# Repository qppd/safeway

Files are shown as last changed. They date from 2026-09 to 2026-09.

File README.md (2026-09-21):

# SafeWay

**An IoT-Based Vehicle Speed Monitoring and Data Logging System for a Campus Security & Safety Unit**

SafeWay is a low-cost, institutional-scale vehicle speed monitoring system. A 24 GHz Doppler radar measures vehicle speed directly on a campus road; a two-board ESP32 design photographs the vehicle, serves a live lane feed, logs the incident to a cloud database via API, and sounds a buzzer when the speed limit is exceeded. Security personnel monitor everything from a web dashboard — in real time.

> Proof-of-concept capstone project (April 2026)

---

## Table of Contents

- [About](#about)
- [How It Works](#how-it-works)
- [Features](#features)
- [Hardware](#hardware)
- [System Architecture](#system-architecture)
- [Repository Structure](#repository-structure)
- [Build Guide](#build-guide)
- [Quick Start (TL;DR)](#quick-start-tldr)
- [Evaluation Criteria](#evaluation-criteria)
- [Documentation Index](#documentation-index)
- [Team](#team)
- [Acknowledgment](#acknowledgment)

## About

Overspeeding inside institutional campuses is monitored manually — by visual observation and paper logging — which is inconsistent and unreliable. Commercial speed-enforcement systems (radar, ANPR cameras) are engineered for highways and priced beyond what small institutions can afford.

SafeWay answers that gap with a **proof-of-concept** built from ~₱2,328 worth of off-the-shelf IoT parts: it measures speed with radar physics, captures evidence, recognizes plate numbers, logs to the cloud, and surfaces violations on a dashboard with a live camera feed — at institutional scale and budget.

Pilot client: a university **Security & Safety Unit (SSU)**. Development follows the **PPDIOO** lifecycle (Prepare, Plan, Design, Implement, Operate, Optimize).

## How It Works

```
Speed = Doppler frequency ÷ 44.7 Hz-per-km/h
```

1. A vehicle enters the radar beam of the **CDM324 24 GHz Doppler module** (mounted on a single pole along the lane)
2. The radar's IF output frequency is **directly proportional to speed** — the ESP32 hub counts pulses, converts Hz → km/h, and holds the **peak** reading for the event
3. Two **KY-008 laser break-beams** across the lane (transmitters on the far post, each on its own supply; receivers on the hub pole) confirm a vehicle is physically present (rejects phantom radar triggers from branches/pedestrians)
4. If peak speed > limit (e.g. 30 km/h campus limit — `SPEED_LIMIT_KPH`):
   - **Buzzer** sounds a live warning while the vehicle is over the limit
   - **Beam #2 breaks → the ESP32-S3 CAM board grabs the photo itself** (vehicle **at the pole**, plate in frame) and caches it; beam #1 breaks → the hub fetches that cached beam-moment frame from `/capture`; the CAM also saves it to microSD
   - When the lane clears, the incident record (speed, raw Doppler Hz, confirm flag, photo) is **POSTed to the cloud API**
5. SSU personnel watch the **live lane feed** and review violations on the dashboard; plate numbers are read from captured photos for record accuracy

## Features

- **Doppler radar speed detection** — direct physical measurement: speed is read from the Doppler shift itself, not timed between two gates
- **Two-board architecture** — 38-pin ESP32 hub owns all sensors; ESP32-S3 CAM owns imaging. WiFi between them, no data cables
- **Live lane feed** — SSU sees the monitored road from the dashboard (polled ~1 frame/s)
- **Dual-sensor confirmation** — radar + laser break-beam agreement flags each incident (evidence-grade: raw Doppler Hz stored with every record)
- **Beam-triggered plate capture** — the camera self-triggers at its own break-beam: zero HTTP latency, car at the pole, plate in frame
- Photo evidence capture with microSD backup logging
- Cloud data logging through REST API integration
- On-site audible overspeed alert (active buzzer)
- Web dashboard for authorized SSU personnel
- Plate number recognition from captured images
- ~₱2,328 prototype cost vs. commercial radar/ANPR systems

## Hardware

Core components (full verified shopping list with Lazada PH links, prices, and ratings: **[docs/BOM.md](docs/BOM.md)**):

| Component | Role |
|---|---|
| CDM324 24 GHz Doppler radar | Speed measurement (IF frequency = 44.7 Hz per km/h) |
| ESP32 38-pin dev board | Sensor hub — pulse counting, beam #1 confirm, buzzer, cloud upload |
| ESP32-S3 WROOM N16R8 CAM + OV5640 | Camera board — beam #2 self-triggered snapshots, polled live feed, microSD backup |
| KY-008 laser TX + receiver pairs ×2 | Beam #1: presence confirmation (hub GPIO 25) · Beam #2: CAM snapshot trigger (GPIO 21) — far-post TXs, hub-pole receivers |
| Active buzzer 5V | Overspeed alert |
| microSD 16GB Class 10 | Local photo backup on the CAM board |
| LM358 op-amp | Radar signal conditioner — CDM324 → LM358 → GPIO 34 (see [HARDWARE.md §4](docs/HARDWARE.md#4-lm358-signal-conditioner-radar-chain)) |
| 5V 2A adapters ×2 + USB chargers ×2 (far post) + 18650 UPS backup per supply (16 cells, 4 devices, 4 h runtime) + IP68 enclosure + breadboard, jumpers, zip ties | Four independent supplies with battery backup, weatherproofing, assembly |

**Complete wiring diagram:** [wiring/circuit_image.png](wiring/circuit_image.png) — every module, pin, and power rail in one picture; visual companion to the pin-by-pin tables in [HARDWARE.md](docs/HARDWARE.md) (editable in [Cirkit Designer](https://app.cirkitdesigner.com/project/192cfce5-5705-47b2-8c56-7a07da66e9da)).

## System Architecture

```mermaid
flowchart TB
    RADAR["CDM324 Doppler radar<br/>IF = 44.7 Hz per km/h"]
    BEAM1["KY-008 pair #1<br/>break-beam across lane"]
    BEAM2["KY-008 pair #2<br/>break-beam across lane (offset)"]
    HUB["ESP32 38-pin HUB — sensors<br/>radar → GPIO 34 · beam #1 → GPIO 25 · buzzer → GPIO 27<br/>peak speed = Hz ÷ 44.7 ÷ cos(mount angle)"]
    CAM["ESP32-S3 WROOM CAM (OV5640)<br/>beam #2 → GPIO 21 → self-triggered snapshot<br/>/capture → cached plate frame + SD save<br/>/stream → polled live frame"]
    API["Cloud API + Database<br/>incident records + photos<br/>plate number recognition"]
    DASH["Monitoring Dashboard (SSU)<br/>live lane feed + violation table + photo pane"]

    RADAR --> HUB
    BEAM1 --> HUB
    BEAM2 --> CAM
    HUB -- "WiFi — fetch cached beam photo, JSON POST" --> CAM
    HUB -- "violation event" --> API
    CAM -- "live feed" --> DASH
    API --> DASH
```

Details: [docs/BLOCK-DIAGRAM.md](docs/BLOCK-DIAGRAM.md) · [docs/SYSTEM-ARCHITECTURE.md](docs/SYSTEM-ARCHITECTURE.md) · [docs/FLOWCHART.md](docs/FLOWCHART.md)

## Repository Structure

```
safeway/
├── README.md               ← you are here
├── docs/
│   ├── BOM.md              ← verified parts list (Lazada PH)
│   ├── HARDWARE.md         ← wiring, power, enclosure assembly
│   ├── FIRMWARE.md         ← both firmware sketches, flashing, tuning
│   ├── BACKEND.md          ← cloud API, database, dashboard
│   ├── TESTING.md          ← calibration & accuracy tests
│   ├── DEPLOYMENT.md       ← site installation guide
│   ├── STACK.md            ← full technology stack reference
│   ├── BLOCK-DIAGRAM.md    ← hardware blocks & signal chains
│   ├── FLOWCHART.md        ← runtime decision logic
│   ├── SYSTEM-ARCHITECTURE.md ← layers, interfaces, failure modes
├── wiring/
│   └── circuit_image.png               ← full circuit diagram (Cirkit Designer)
│   └── CDM324_LM358_ESP32_Testing_Guide.md  ← step-by-step LM358 build & test guide
├── .gitignore              ← repo hygiene rules
└── LICENSE                 ← CC BY 4.0
```

## Build Guide

The complete build is organized into six stage guides. Follow them in order:

| Step | Guide | What you'll do |
|---:|---|---|
| 1 | **[docs/HARDWARE.md](docs/HARDWARE.md)** | Verify the radar's IF output, wire the hub (radar + laser break-beam #1 + buzzer) and the CAM (break-beam #2 → GPIO 21), set up the CAM board, assemble into the enclosure |
| 1a | **[wiring/CDM324_LM358_ESP32_Testing_Guide.md](wiring/CDM324_LM358_ESP32_Testing_Guide.md)** | Step-by-step LM358 signal conditioner build & test — power, 2.5V bias, Stage 1 & 2 amps, radar input, comparator gate before connecting to ESP32 GPIO34 |
| 2 | **[docs/FIRMWARE.md](docs/FIRMWARE.md)** | Set up Arduino IDE, flash both boards (camera server + sensor hub), tune speed limit + angles |
| 3 | **[docs/BACKEND.md](docs/BACKEND.md)** | Stand up the cloud API + database + monitoring dashboard with live feed |
| 4 | **[docs/TESTING.md](docs/TESTING.md)** | Bench-test each board, calibrate Doppler accuracy, run the ISO-based evaluation |
| 5 | **[docs/DEPLOYMENT.md](docs/DEPLOYMENT.md)** | Site survey, pole-mount at the pilot road, train SSU users, maintenance plan |

Each guide is self-contained with wiring tables, commands, and checklists.

## Quick Start (TL;DR)

```bash
git clone https://github.com/qppd/safeway.git
```

1. Order parts from [docs/BOM.md](docs/BOM.md) (~₱2,328 recommended build)
2. Wire per [HARDWARE.md](docs/HARDWARE.md) → flash both boards per [FIRMWARE.md](docs/FIRMWARE.md)
3. Launch the API per [BACKEND.md](docs/BACKEND.md), point the hub firmware at it
4. Drive past the pole — verify speed reading + photo + dashboard record + live feed

## Evaluation Criteria

Per the capstone methodology, the prototype is evaluated on:

| Criterion | Measure |
|---|---|
| Accuracy | Correct speed detection and recorded data |
| Response Time | Detection → alert + data transmission latency |
| Reliability | Consistency across repeated tests |
| Usability | Dashboard ease-of-use for SSU personnel |
| Data Accessibility | Real-time record retrieval |

Software quality is assessed against **ISO/IEC 25010** and the IoT architecture against **ISO/IEC 30141**. See [docs/TESTING.md](docs/TESTING.md).

## Documentation Index

| Document | Contents |
|---|---|
| [BOM.md](docs/BOM.md) | Verified Lazada PH parts, prices, ratings, seller links, budget variants |
| [HARDWARE.md](docs/HARDWARE.md) | Two-board pin map, wiring tables, power design, enclosure, radar aiming |
| [FIRMWARE.md](docs/FIRMWARE.md) | Both annotated sketches (camera server + sensor hub), flashing, tuning |
| [BACKEND.md](docs/BACKEND.md) | REST API spec, database schema, dashboard + live feed, plate recognition |
| [TESTING.md](docs/TESTING.md) | Per-board bench tests, Doppler calibration, evaluation protocol + logs |
| [DEPLOYMENT.md](docs/DEPLOYMENT.md) | Site survey checklist, pole mounting, training, maintenance |
| [STACK.md](docs/STACK.md) | Full technology stack — firmware, backend, frontend, rationale |
| [BLOCK-DIAGRAM.md](docs/BLOCK-DIAGRAM.md) | Hardware blocks, signals, power distribution |
| [FLOWCHART.md](docs/FLOWCHART.md) | Runtime logic — event pipeline, server pipeline, dashboard flow |
| [SYSTEM-ARCHITECTURE.md](docs/SYSTEM-ARCHITECTURE.md) | Layers, component responsibilities, interfaces, failure modes |
|| [wiring/circuit_image.png](wiring/circuit_image.png) | Full circuit diagram — hub, radar, both break-beams, buzzer, far-post lasers ([Cirkit Designer project](https://app.cirkitdesigner.com/project/192cfce5-5705-47b2-8c56-7a07da66e9da)) |
|| [wiring/CDM324_LM358_ESP32_Testing_Guide.md](wiring/CDM324_LM358_ESP32_Testing_Guide.md) | Step-by-step LM358 signal conditioner build & test — power, 2.5V bias, Stage 1 & 2 amps, radar input, comparator gate before connecting to ESP32 GPIO34 |

## Author

**[QPPD](https://github.com/qppd)**

## Acknowledgment

Pilot client: a university **Security & Safety Unit**. This project follows the PPDIOO network lifecycle framework (Cisco). The full academic manuscript is kept private and is available from the team on request.

Per the capstone disclaimer, this repository is licensed under **[CC BY 4.0](LICENSE)** — free to copy and distribute provided the source is acknowledged.

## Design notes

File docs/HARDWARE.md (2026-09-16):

# Hardware Assembly Guide

Wiring, power, and enclosure build for the SafeWay prototype (two-board architecture). Order parts first from [BOM.md](BOM.md).

**Estimated time:** 2–3 hours first build (two boards to wire + the radar verification step)

---

## Tools Required

- Multimeter (continuity + voltage checks)
- Small Phillips screwdriver, drill + 8–10 mm bit (buzzer port / cable glands), file
- Double-sided foam tape / hot glue (module mounting)
- A couple of resistors (10 kΩ + 20 kΩ) — only if the radar's OUT swing needs a divider (§3)
- Optional but ideal for §3: cheap oscilloscope, or 3.5 mm audio cable + laptop mic-input app (free scope apps work fine — Doppler signals are audio-band)

---

## 1. System Overview

A single pole-mounted unit watches the lane. The **CDM324 24 GHz Doppler radar** measures vehicle speed directly from the Doppler frequency shift; the **ESP32-S3 WROOM N16R8 CAM board** (OV5640) photographs the vehicle and serves a live stream; the **ESP32 38-pin hub** counts Doppler pulses, watches **laser break-beam #1** (KY-008 transmitter on a far post, receiver module on the hub pole — a vehicle crossing the lane breaks the beam), sounds the buzzer on overspeed, and logs the incident to the cloud API when the lane clears. The CAM board watches its own **break-beam #2** (second KY-008 pair, aimed across the same lane) — the instant beam #2 breaks, the CAM **self-triggers the snapshot** (vehicle at the pole, plate in frame) and caches it for the hub's fetch. **No cables cross the road** — each far-post laser TX runs on its own small supply; all intelligent boards meet over WiFi.

```mermaid
flowchart LR
    subgraph FAR["FAR POST — opposite side of the lane"]
        direction TB
        TX1["KY-008 laser TX #1<br/>red dot, always-on<br/>own supply #1"]
        TX2["KY-008 laser TX #2<br/>second pair, same lane,<br/>slightly offset — own supply #2"]
    end
    subgraph HUBPOLE["HUB POLE — single pole-mounted unit"]
        direction TB
        RX1["Laser receiver #1 module<br/>DO → GPIO 25<br/>event confirm — beam #1"]
        RX2["Laser receiver #2 module<br/>DO → GPIO 21 on CAM<br/>self-triggered snapshot"]
        HUB["ESP32 38-pin HUB<br/>CDM324 → LM358 → GPIO 34<br/>Buzzer → GPIO 27<br/>WiFi — fetches CAM photo, POSTs to API"]
        CAM["ESP32-S3 WROOM CAM<br/>OV5640 /capture — cached plate frame<br/>/stream — polled live frame<br/>microSD — local backup of every photo"]
    end
    CLOUD["☁ Cloud API + Dashboard"]

    TX1 -. "beam #1 crosses the lane" .-> RX1
    TX2 -. "beam #2 crosses the lane" .-> RX2
    RX1 --> HUB
    RX2 --> CAM
    HUB -- "campus WiFi" --> CLOUD
    CAM -- "campus WiFi" --> CLOUD
```

**The only physics you need:** the CDM324 outputs a signal whose frequency is speed:

```
f_doppler (Hz) = 44.7 × speed (km/h)
```

A car at 30 km/h → ~1,341 Hz on the OUT pin. The hub counts pulses over a window and divides — that's the whole speed measurement chain.

**Why two boards:** the classic single-board ESP32-CAM starves pins (camera + SD leaves ~2 usable GPIOs — no room for radar, break-beam, buzzer). The new ESP32-S3 camera board has GPIOs to spare — one of them (GPIO 21) now takes break-beam #2 — but the split stays: radar pulse-counting never competes with camera DMA for the same core, and a camera reboot (heap fragmentation etc.) can never disturb a speed measurement in progress. Each board is simpler to code, flash, and debug on its own.

---

## 2. The Two Boards

### 2.1 ESP32 38-pin (sensor hub)

Standard DOIT DevKit v1-compatible 38-pin board (CP2102, Type-C or micro-USB). All its GPIOs are free — no camera driver hogging them. SafeWay uses just 3 GPIOs (radar, beam #1 receiver, buzzer), leaving 30+ spare for future sensors (PIR, RGB status LED, rain gauge…).

**Board quirks to know:**
- GPIO 34/35/36/39 are **input-only** — perfect for the radar OUT (never needs to drive).
- GPIO 6–11 are flash pins — **never wire anything to them**.
- GPIO 0 is the boot strap — leave it alone or the board won't boot reliably.

**Pin map:**

| GPIO | SafeWay assignment | Notes |
|---|---|---|
| **34** (input-only) | **CDM324 OUT via LM358 conditioner (§4)** — Doppler pulses | Input-only pin: the conditioner only ever drives it; ideal |
| **25** | **Laser receiver #1 DO** (beam broken/OK) | digital in; receiver is a 3.3 V-safe comparator output — see §5.2 note |
| **27** | Buzzer + | any OUTPUT-capable GPIO |
| 32/33 | spare (I2C bus) | future sensors |
| 4/16/17/18/19/21/22/23/26 | spare (SPI/UART2 etc.) | future modules |

**Boot & WiFi safety audit (why these exact pins):**

| GPIO | Pin class on ESP32-WROOM-32 | Safe for our use? |
|---|---|---|
| 34 | Input-only — no strap role, no WiFi role | ✅ radar OUT drives it push-pull |
| 25 | ADC2 channel / DAC1 | ✅ digital beam input only (comparator DO) |
| 27 | ADC2 channel / touch T7 | ✅ digital buzzer output |

- The "GPIO 25/26/27 conflict with WiFi" rule is real but applies **only to `analogRead()`** — the WiFi driver owns the ADC2 peripheral, so analog reads on those pins fail while WiFi is active. **Digital I/O and interrupts are unaffected**; this firmware never calls analog functions.
- **Strapping pins 0, 2, 5, 12, 15 are entirely avoided** — nothing can pull the boot mode, change flash voltage (the classic GPIO-12 killer), or silence boot logs.
- Flash pins **6–11** and UART0 **1/3** untouched.
- **GPIO 34 has no internal pull-up/down** (true for all of 34–39): the CDM324's amplified OUT drives it push-pull so nothing is needed — but if the signal ever reads flaky, add an external **10 kΩ pull-up to 3.3 V**. Don't rely on `INPUT_PULLUP` on 34–39; it silently does nothing.
- **Laser receiver on GPIO 25 (has internal pull-ups):** the receiver's open-comparator DO idles at a defined level with `INPUT_PULLUP` enabled — no external resistor needed.
- Interrupt load is trivial: the radar ISR is a single increment (≤ ~4,470 pulses/s at 100 km/h); the beam ISR fires only on state changes (a car passes = 2 edges), debounced in software.

### 2.2 ESP32-S3 WROOM N16R8 CAM (camera board)

Standalone ESP32-S3-WROOM-1 **N16R8** board (16 MB flash, 8 MB octal PSRAM) with the **OV5640 5 MP camera** on a 24-pin DVP FPC header and an **onboard microSD slot**. No programmer board, no FTDI, no IO0 jumper — two Type-C ports (one CH343P USB-serial for flashing, one native USB-OTG).

**Camera board pin facts** (from the board's pinout diagram, cross-checked against the xiaozhi-esp32 `bread-compact-wifi-s3cam` config — 14/14 camera pins match):
- Camera DVP bus: Y2–Y9 = GPIO 11, 9, 8, 10, 12, 18, 17, 16 · XCLK 15 · PCLK 13 · VSYNC 6 · HREF 7 · SIOD 4 · SIOC 5 · PWDN/RESET not wired.
- microSD (1-bit SD_MMC): CLK = GPIO 39 · CMD = GPIO 38 · D0 = GPIO 40.
- The 24-pin header accepts OV2640/OV7725/OV3660/OV5640 — OV5640 is the fitted 5 MP unit.
- Still dedicated in this project: **power it, aim it, flash it — and watch its own break-beam #2**. Spare GPIOs (1, 2, 14, 47, 48…) stay free for future on-board peripherals.
- **Laser receiver #2 DO → GPIO 21** (`INPUT_PULLUP` works on the S3 — unlike the hub's input-only GPIO 34). Clean pin: no camera role, no SD role, no strap role. **Verify DO swing with a multimeter before wiring** — the S3 is **not 5 V tolerant**; if DO swings toward 5 V, the 10 kΩ + 20 kΩ divider is mandatory ([§5.3](#53-main-wiring--cam-board--beam-2)).

> **3.3 V logic only:** the ESP32-S3 GPIOs are **not 5 V tolerant** (unlike the classic WROOM-32 hub, which survives it). Never feed 5 V into any S3 pin — including its camera/SD lines.

---

## 3. IF Signal Verification (do this first!)

Before enclosure or firmware, verify what your radar module's OUT pin actually outputs. Seller listings swap boards — spend 10 minutes on the bench:

1. **Power the module:** 5 V to VCC, GND to GND (module silkscreen shows 3–4 pins: VCC, GND, OUT, sometimes a second GND).
2. **Scope the OUT pin** (or feed it into a laptop mic input via a 1 µF coupling cap):
   - **Idle:** near-flat DC, maybe low-frequency noise.
   - **Wave your hand at the module from 1–2 m:** a **rough sine/square wave in the 100–2,000 Hz range** (hand moving ~10–40 km/h equivalent).
   - A fan spinning in front produces a steady tone.
3. **Measure the amplitude:** swing ≤ 3.3 V → wire OUT **directly** to GPIO 34. Swings toward 5 V → add the divider:

```
 CDM324 OUT ──[10 kΩ]──┬──► ESP32 GPIO 34
                       [20 kΩ]
                        │
                       GND
```
(Divides 5 V → 3.3 V. Any nearby 2:1 ratio pair works.)

**If you see only a motion on/off level (flat HIGH when moving)** — the board is a presence-switch variant, not a Doppler-output variant. Return it; the speed design needs the frequency output. (BOM has backups.)

**Record in your build log:** OUT idle level, swing amplitude, waveform at hand-wave. Evidence for the paper's hardware validation section.

---

## 4. LM358 Signal Conditioner (radar chain)

The hub's radar chain is **CDM324 → LM358 (two-stage ≈ ×101 amplifier) → GPIO 34**. Run §3 first anyway: if your module's OUT already swings healthy pulses it can drive GPIO 34 directly, but the LM358 stage is fitted in this build so even weak-IF module batches produce a clean, mid-rail-biased trigger.

**Parts (BOM #5):** LM358 DIP-8 · C1 10 µF, C2 2.2 µF ×2, C3 10 µF (electrolytic, + toward the previous stage) · 10 kΩ ×4, 1 MΩ ×2 · 100 nF ceramic · 8-pin socket.

```
 CDM324 OUT ──[C1 10µF]──┬──[R1 10k]── GND
                         │  [R1b 10k from 5 V]     (bias IF at Vcc/2 = 2.5 V)
                         ├──► pin 3 (A+)
 pin 2 (A−) ──[R3 10k in series with C2 2.2µF]── GND
 pin 1 (A out) ──[R2 1M]── pin 2                 (gain ≈ 101)
 pin 1 ──[C3 10µF]──► pin 5 (B+)
 pin 6 (B−) ──[R3 10k in series with C2 2.2µF]── GND
 pin 7 (B out) ──[R2 1M]── pin 6                 (gain ≈ 101)
 pin 7 ──► ESP32 GPIO 34
 pin 8 = 5 V (100 nF ceramic to GND right at the IC) · pin 4 = GND
 pins 3 & 5 tie to the 2.5 V bias node
```

- **Gain per stage ≈ 101** (R2/R3); two stages ≈ ×10,000. The C2 caps set DC gain to 1 — outputs idle at the 2.5 V bias instead of slamming a rail — and with the LM358's ~1 MHz GBW the chain passes ≈ **7 Hz–6 kHz** (≈ 0.16–138 km/h).
- **Power from the 5 V rail (supply #3), GND common with the ESP32.** Pin 7 idles ~2.5 V and swings 0–~3.5 V — safe for the WROOM-32's GPIO 34.
- **Bench check after building:** repeat §3's hand-wave test — ~0 Hz idle, hundreds of Hz on hand movement at 1–3 m. A flat pinned output means a stage is railing: re-check the 2.5 V bias node and C2 polarity.
- **Prebuilt shortcut:** the "LM358 100× Gain Signal Amplification Module" (₱148, BOM) replaces the discrete build — IF into IN, OUT to GPIO 34, trim idle to mid-rail.

**Reference builds:** [Easy HB100 Amplifier (Instructables)](https://www.instructables.com/Easy-HB100-Amplifier/) — same LM358 topology · [3zuli/HB100_test (GitHub)](https://github.com/3zuli/HB100_test) — doppler + pre-amp + Arduino code. For the radar itself: [kd8bxp/24ghzdoppler](https://github.com/kd8bxp/24ghzdoppler) (ICStation CDM324 test code) · [Andreas Spiess #181 — DIY radar speed gun for Arduino/ESP32](https://www.youtube.com/watch?v=Kzsh59TM4MY).

---

## 5. Wiring Tables

> **Full wiring diagram:** [`wiring/circuit_image.png`](../wiring/circuit_image.png) — every module, pin, and power rail in one picture (editable: [Cirkit Designer project](https://app.cirkitdesigner.com/project/192cfce5-5705-47b2-8c56-7a07da66e9da)). The tables below remain the authoritative pin-by-pin reference.

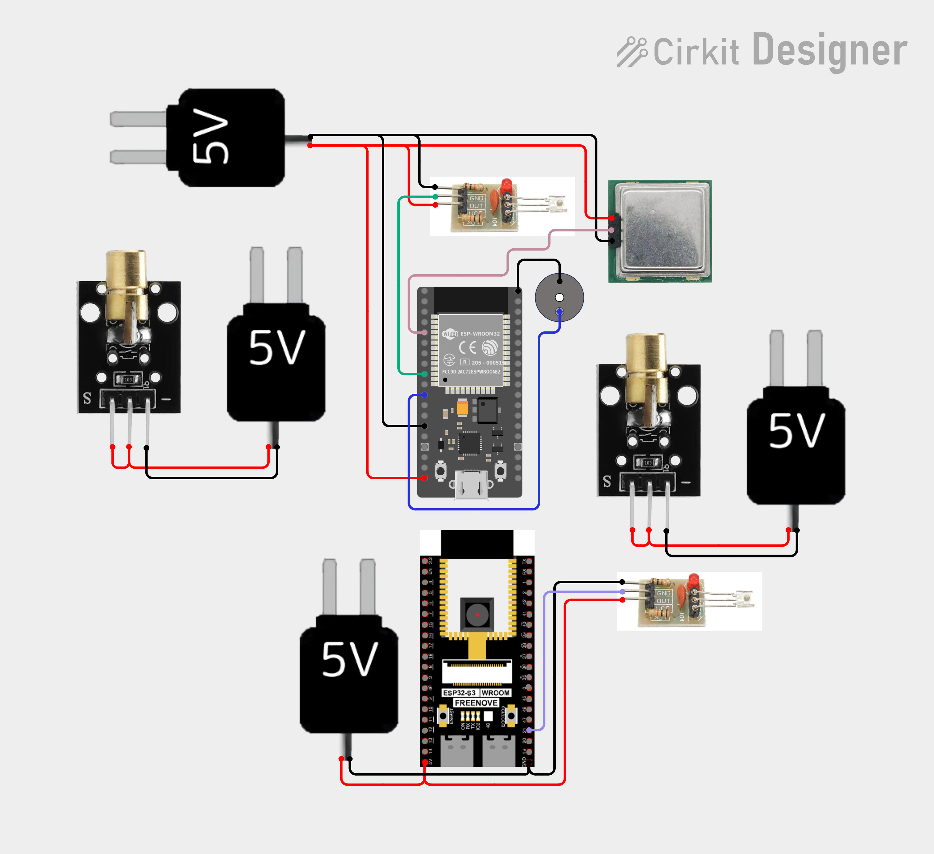
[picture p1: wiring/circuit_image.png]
SafeWay full wiring diagram


### 5.1 Programming setup (bench only)

| Board | PC |
|---|---|
| ESP32 38-pin USB | USB cable |
| ESP32-S3 CAM USB-C (either port) | USB cable |

Each board flashes itself over its own USB. The CAM board's CH343P does the flash dance for you — no IO0 jumper. (Driver + Arduino board-settings notes in [FIRMWARE.md](FIRMWARE.md).)

### 5.2 Main wiring — 38-pin hub (radar + beam #1 + buzzer)

| Module | Pin | Connect to |
|---|---|---|
| CDM324 radar | VCC | 5V rail (supply #3) |
| | GND | GND |
| | OUT | C1 10 µF → **LM358 stage A input** (§4) |
| **LM358 conditioner** (§4) | V+ / GND (pins 8 / 4) | 5V rail (supply #3) / GND — 100 nF at the IC |
| | OUT (pin 7) | **GPIO 34** (idles ~2.5 V — safe) |
| **Laser receiver #1** (hub pole) | VCC | 5V rail (supply #3) |
| | GND | GND |
| | DO | **GPIO 25** (`INPUT_PULLUP`) |
| | AO (if present) | leave unconnected |
| **KY-008 laser TX #1** (far post) | S | 5 V from its **own supply #1** *(always-on)* |
| | middle (+) | 5 V supply #1 |
| | − | GND supply #1 |
| Active buzzer | + | **GPIO 27** |
| | − | GND |

**Laser receiver level note:** most laser-receiver modules in this family (the "Non-Modulator Tube Laser Receiver" / KY-008-pair type) run a 5 V supply but output a **3.3 V-safe digital DO** from an LM393-style comparator — still, **measure DO once with a multimeter** (beam open vs blocked) before trusting it: if it swings to ~5 V, add the same **10 kΩ + 20 kΩ divider** as the radar's. If your module has an **AO (analog) pin**, ignore it — we only use DO.

**Beam polarity — check once, code-free:** power the pair on the bench, aim TX at receiver, and watch the receiver board's onboard LED (most have one): typically **LED ON / DO LOW = beam intact**, **LED OFF / DO HIGH = beam broken**. The firmware's `BEAM_BREAKS_LOW` constant matches whichever polarity your module uses — set it after this bench check ([FIRMWARE.md §5](FIRMWARE.md#5-tuning-constants)). Do this for **both** beam pairs — each receiver has its own polarity constant (`BEAM_BREAKS_LOW` on the hub, `CAM_BEAM_BREAKS_LOW` on the CAM).

**Far-post laser mounting:** both KY-008 TX modules live on the far post, each in a small weatherproof box or under an overhang, dots aimed across the lane at their receivers (TX #1 → receiver #1 on the hub, TX #2 → receiver #2 on the CAM board). Mount both ends at the same height (plate height is ideal: ~50 cm) so the beams cross where plates are; offset the two beams by a few cm along the lane so a vehicle body blocks each in turn. Keep the dots small — at ≤ 10 m a 6 mm copper-head module holds a tight dot without optics.

### 5.3 Main wiring — CAM board (beam #2)

| Module | Pin | Connect to |
|---|---|---|
| ESP32-S3 WROOM CAM | Type-C USB (either port) or 5V/VIN pin | its own 5V supply #4 |
| | microSD (onboard slot) | 16 GB FAT32, inserted before power |
| OV5640 camera | 24-pin FPC header (fitted) | aimed at the trigger zone |
| **Laser receiver #2** (hub pole) | VCC | 5V rail (supply #4) |
| | GND | GND |
| | DO | **GPIO 21** (`INPUT_PULLUP`) — **divider mandatory if DO swings >3.3 V: the S3 is not 5 V tolerant** |
| | AO (if present) | leave unconnected |
| **KY-008 laser TX #2** (far post) | S | 5 V from its **own supply #2** *(always-on)* |
| | middle (+) | 5 V supply #2 |
| | − | GND supply #2 |

### 5.4 Power design — four independent supplies

```mermaid
flowchart LR
    subgraph FARPOST["FAR POST — no cable crosses the road"]
        direction TB
        S1["Supply #1 — 5V 1A+<br/>+ 18650 backup (§5.5)"]
        S2["Supply #2 — 5V 1A+<br/>+ 18650 backup (§5.5)"]
        TX1["KY-008 TX #1<br/>under 30 mA, always-on"]
        TX2["KY-008 TX #2<br/>under 30 mA, always-on"]
        S1 --> TX1
        S2 --> TX2
    end
    subgraph HUBPOLE["HUB POLE — enclosure at the outlet"]
        direction TB
        S3["Supply #3 — 5V 2A<br/>+ 18650 backup (§5.5)"]
        HUB["38-pin HUB"]
        RADAR["CDM324 radar<br/>30–60 mA"]
        RX1["Laser receiver #1<br/>≈5 mA"]
        BUZ["Buzzer<br/>GPIO-driven"]
        S3 --> HUB
        S3 --> RADAR
        S3 --> RX1
        S3 --> BUZ
        S4["Supply #4 — 5V 2A<br/>+ 18650 backup (§5.5)"]
        CAM["ESP32-S3 CAM<br/>board reg makes 3.3V"]
        RX2["Laser receiver #2<br/>≈5 mA"]
        S4 --> CAM
        S4 --> RX2
    end
```

- **Four supplies, zero shared rails by design:** each far-post laser TX is independent (a dead supply #2 can't dim beam #1), the hub's measurement rail is isolated from the CAM's camera/WiFi peaks (a CAM reboot can't brown-out the radar), and the CAM's rail is isolated from the hub's buzzer/WiFi bursts. No supply failure cascades. **Each supply carries its own 18650 UPS branch (§5.5)** — a mains outage bumps every rail to battery with no controller or relay.
- **Far-post supplies:** any compact 5V ≥1A source — a USB charger + short cable, a small DC adapter, or a power-bank-for-mains style module — inside each TX's weatherproof housing. No cable crosses the road.
- Add a 470–1000 µF electrolytic across the hub's 5V rail (supply #3).
- **Radar stability:** keep a cap near the radar's VCC/GND pair so WiFi bursts don't modulate the radar supply (phantom low-speed readings).
- **Bench alternative:** for bench testing you can consolidate to one supply per enclosure side + beefy 1000 µF rail caps — acceptable for testing only; field builds keep all four isolated.

### 5.5 Battery backup (UPS option) — one 18650 per supply

Each of the four supplies gets an identical bolt-on backup so a mains outage never stops a measurement, a snapshot, or a beam:

```
 MAINS 220 V
    │
 ┌──▼──────────────┐ 5 V ──[SS34 Schottky]──┬──► supply rail (hub / CAM / TX)
 │ wall adapter    │                        │
 │ (BOM #10/#12)   │                        │
 └─────────────────┘                        │
        5 V                                 │
        └──► TP4056 ── 18650 bank ──► MT3608 (set 5.0 V) ──┘
             (1 A)     in holder
```

- **Mains wins while present:** the adapter holds its rail at ~5.1–5.2 V; the battery branch sits behind an MT3608 set to **5.0 V**, so it sources only when the rail sags below that (outage/brownout). Bumpless transfer — no controller, no relay. The **SS34 blocks the rail from backfeeding the charger** — fit it on the mains branch only.
- **Charging:** TP4056 charges at 1 A — ~4 h for a single 3500 mAh cell. Protected cells (LiitoKala Lii-35S+) cut off at 2.5 V; the MT3608's UVLO ends discharge before damage. No fuse and no paralleling in this design — each rail carries exactly one protected cell.
- **Keep the 470–1000 µF rail cap** — it carries the WiFi/buzzer burst during the transfer instant.

**Sizing — 4 h max runtime from measured rail currents:**

| Rail | Draw | Energy for 4 h | 18650 3500 mAh cells | Depth of discharge |
|---|---|---|---|---|
| Supply #3 — hub (radar + LM358 + RX1 + buzzer + WiFi) | ≈ 350 mA | 1.4 Ah ÷ 0.85 ≈ 1.65 Ah | **1** | ≈ 47% |
| Supply #4 — CAM (S3 + OV5640 + RX2 + stream) | ≈ 350 mA | same | **1** | ≈ 47% |
| Supply #1 — KY-008 TX #1 (far post) | < 30 mA | 0.12 Ah ÷ 0.85 ≈ 0.14 Ah | **1** | ≈ 4% |
| Supply #2 — KY-008 TX #2 (far post) | < 30 mA | same | **1** | ≈ 4% |

**Per device: 4 cells (one per supply — hub, CAM, and both far-post laser TXs) → 4 devices/poles = 16 cells.** One cell per rail means no paralleling and no balancing; the hub/CAM cells see ≤ ≈ 47% DoD per outage — gentle on cycle life, and the TX cells barely notice it (≈ 4%).

- **Far post gets a battery too:** the TX's backup branch (charger + single holder + cell + TP4056/MT3608/SS34) needs a slightly bigger housing — use a small IP65 box (BOM Deluxe option) instead of tucking the charger under the post cap. The beam never dies in an outage.

**Bench validation before deployment:** pull the mains plug — the rail must hold ≥ 4.9 V, the hub serial keeps counting Hz, the CAM stream doesn't drop. Recharge and repeat; log one full 4 h outage test per device before acceptance (TESTING.md).

Shopping list with verified Lazada links: **[BOM.md — Battery Backup Add-On](BOM.md#battery-backup-add-on-ups--18650--4-devicespoles)**.

---

## 6. microSD Preparation (CAM board)

1. Format **FAT32** (Windows: right-click drive → Format → FAT32, 32 KB clusters).
2. Class 10 / U1 minimum — capture stalls below this.
3. Insert **before** powering (hot-insert is unreliable).
4. 16 GB holds ~40,000 JPEGs at SVGA — weekly rotation is plenty.

---

## 7. Enclosure Assembly (IP68 ABS, 200x100x70 mm)

1. **Layout:** 830-point breadboard + 38-pin board (hub) on one side; ESP32-S3 CAM board on the other; radar module centered behind the front wall; terminal strip for power in/out.
2. **Radar mounting:** 24 GHz passes through **ABS plastic** (not metal). Mount the CDM324 **inside** the sealed box facing out through the plastic wall — zero apertures for rain. Antenna face within ~2 cm of the wall.
   - Never put metal (screws, brackets, foil) between radar and road.
3. **Laser receiver placement (×2):** mount receiver #1 and receiver #2 inside the enclosure side by side behind a small clear window each (drill ~10–12 mm, seal with silicone or a glue-lined washer) — each photodetector just needs to see its far-post dot. Aim both windows at the **beam axis** (straight across the lane).
4. **Far-post KY-008 TX ×2:** each in its own weatherproof housing (a small IP65 box — it now holds the 5V supply **plus the 18650 UPS branch**: holder + TP4056/MT3608/SS34), dot aimed at its receiver window. Offset the two dots a few cm along the lane so the beams break in sequence as a vehicle passes.
5. **Buzzer:** small drilled port (8 mm) covered with tape.
6. **Camera window:** large cutout + clear acrylic/PETG sealed with silicone. OV5640 must see the lane at plate height.
7. **Cable glands:** one for DC power in (supply #3), one for supply #4, one spare for future sensor. Glue-lined heat shrink. (No gland for the far-post run — nothing crosses the road anymore.)
8. **Desiccant pack** inside — tropical humidity fogs lenses.
9. Breadboard sticks down with double-sided foam tape (removable for iteration).

---

## 8. Radar Aiming Procedure (replaces gate alignment)

1. **Mount the pole unit** so the radar beam runs **along the traffic direction**, angled **≤15° off the lane axis** (10–15° sweet spot: enough angle to not be a head-on reflector, small enough that cosine error stays under 4%).
2. **Cosine error, the one number to know:** radar measures speed along the beam — Measured = true × cos(θ):

| Aiming angle θ off traffic axis | Reading error |
|---|---|
| 0° | 0% |
| 10° | −1.5% |
| 15° | −3.4% |
| 30° | −13.4% (re-aim) |

   The firmware's `COSINE_ANGLE_DEG` constant compensates; keep θ small or set the measured install angle.
3. **Field of view:** clear the beam corridor (a ~15–30° cone) of **swaying branches, banners, AC condenser fans, parked vehicles** — anything moving inside the cone reads as a target.
4. **Beam alignment (one-time, two-person, ×2 pairs):** one person holds a white card at each receiver window in turn; the other nudges the far-post KY-008s until each red dot lands on its receiver's photodetector (receiver LED flips → dot is on target). At ≤ 10 m the dot barely diverges — align once at install and it holds. Re-check after typhoons (a knocked far post is the #1 beam failure mode).
5. **Bench-verify first:** serial shows Hz values on a hand-wave 1–3 m out, ~0 Hz when still. Then graduate to vehicles ([TESTING.md](TESTING.md)).
6. Re-check aim after typhoons — a knocked-5° pole quietly adds cosine error to every record.

---

## 9. Assembly Checklist

- [ ] §3 IF verification done — waveform confirmed, amplitude recorded, divider fitted if needed
- [ ] Hub pins: radar→LM358 (§4)→34, receiver #1 DO→25 (divider only if measured >3.3 V), buzzer→27
- [ ] CAM pins: receiver #2 DO→GPIO 21 (S3 — divider **mandatory** if DO >3.3 V), `CAM_BEAM_BREAKS_LOW` polarity recorded
- [ ] KY-008 bench check ×2: TX dots visible, both receiver LEDs flip when blocked, both DO polarities recorded
- [ ] Both boards power up independently on their own supplies (#3 hub, #4 CAM); TX #1/#2 each powered by supplies #1/#2 at the far post
- [ ] CAM board: microSD FAT32 in before power; camera focused on trigger zone
- [ ] 5V rails measure 4.8–5.2 V under WiFi load; cap installed near the radar
- [ ] 18650 backup fitted per §5.5: SS34 orientation checked, MT3608 pre-set to 5.0 V before connecting a load, cells fully charged before install; pull-the-plug test passed
- [ ] Radar faces out through ABS wall, no metal in the beam corridor
- [ ] Both receiver windows drilled + sealed; both far-post TX housings sealed with their supplies + 18650 UPS branches inside (IP65 box); **no cable crosses the road**
- [ ] Camera window clear, desiccant in, glands sealed
- [ ] Serial: ~0 Hz idle noise floor, Hz spikes on hand movement; beam #1 blocked → hub prints `BEAM BROKEN`; beam #2 blocked → CAM serial prints `BEAM2 SNAP → SD ok`; beam blocked mid-event → hub's photo fetch returns the CAM-cached frame

---

Build chain: [BOM](BOM.md) → **HARDWARE** → [FIRMWARE](FIRMWARE.md) → [BACKEND](BACKEND.md) → [TESTING](TESTING.md) → [DEPLOYMENT](DEPLOYMENT.md)

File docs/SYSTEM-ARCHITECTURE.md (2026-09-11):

# System Architecture

Layers, boundaries, and interfaces — how SafeWay is organized as a system, from photons to dashboard. Diagrams are **Mermaid** and render natively on GitHub.

---

## 1. Layered View

```mermaid
flowchart TB
    L5["L5 · PRESENTATION<br/>SSU browser: dashboard.html — Tailwind + vanilla JS<br/>table · photo pane · live feed"]
    L4["L4 · APPLICATION<br/>FastAPI :8000 — POST/GET/PATCH incidents<br/>photo serve · cam-status · dashboard hosting"]
    L3["L3 · DATA &amp; INTELLIGENCE<br/>SQLite (incidents) · uploads/ store<br/>plate recognition (OpenCV + Tesseract)"]
    L2["L2 · EDGE DEVICES<br/>ESP32 hub: sensing + event logic + reporting<br/>ESP32-S3 CAM: beam-triggered evidence + stream"]
    L1["L1 · SENSING &amp; PHYSICS<br/>CDM324 Doppler radar · KY-008 beam pair #1 (confirm)<br/>KY-008 beam pair #2 (CAM snapshot trigger)<br/>OV5640 imager · buzzer"]
    L1 -- "GPIO electrical" --> L2
    L2 -- "WiFi HTTP" --> L4
    L4 -- "HTTP / HTML" --> L5
    L3 --- L4
```

**Key boundary decisions:**

- **Sensing on the edge, intelligence on the server.** The hub does physics (Hz→km/h), thresholding, and event assembly — everything that must happen in real time. The server does OCR and storage — everything that can wait. A 300 ms loop on the hub never competes with plate recognition on the server.
- **Two boards, one job each.** The ESP32-S3 camera board has pins and PSRAM to spare, but the split stays: sensors and imaging in separate fault domains means a camera crash can't take down speed measurement (and vice versa).
- **Evidence has two paths.** Photo goes hub→server immediately when WiFi is up; microSD on the CAM is the durable copy either way. The system degrades gracefully, never loses evidence.

## 2. Component Responsibilities

| Component | Owns | Never does |
|---|---|---|
| CDM324 radar | IF pulse generation (44.7 Hz/km/h) | — |
| Break-beam pair #1 | presence edge across the lane (hub side) | speed (radar's job) |
| Break-beam pair #2 | snapshot trigger edge across the lane (CAM side) | speed or event confirm |
| ESP32 hub | pulse counting, beam #1 ISR+debounce, Hz→km/h, cosine correction, peak-hold, buzzer, beam-break photo fetch, incident POST | OCR, long-term storage |
| ESP32-S3 CAM | beam #2 self-triggered capture, PSRAM photo cache, `/capture` serving, polled live frame, microSD save | speed logic, upload |
| FastAPI server | validation, server-side timestamps, photo storage, OCR orchestration, dashboard hosting | sensing decisions |
| Dashboard | read, filter, review, view live feed | write raw records (only PATCH review) |

## 3. Interfaces (the contract set)

| # | Interface | Protocol | Contract |
|---|---|---|---|
| I1 | Radar OUT → hub GPIO 34 | electrical, RISING ISR | pulses; rate ∝ speed |
| I2 | Beam #1 RX DO → hub GPIO 25 | electrical, CHANGE ISR | level encodes intact/broken (`BEAM_BREAKS_LOW`) |
| I3 | Buzzer ← GPIO 27 | electrical | HIGH = over limit |
| I4 | Beam #2 RX DO → CAM GPIO 21 | electrical, CHANGE ISR | break edge → self-triggered snapshot; level polarity `CAM_BEAM_BREAKS_LOW` |
| I5 | Hub → CAM `GET /capture` | WiFi HTTP | fires at beam #1 break (vehicle at the pole); returns the CAM's cached beam-moment JPEG if fresh, else a live grab (+ SD save) |
| I6 | Browser → CAM `GET /stream` | LAN HTTP, polled ~1/s | one JPEG per request — pseudo-live, direct, no server relay |
| I7 | Hub → API `POST /api/incidents` | WiFi HTTP JSON | device_id, speed_kph, limit_kph, doppler_hz, confirmed, photo_b64 → 201 |
| I8 | Browser → API GET/PATCH | HTTP JSON | list/filter incidents; mark reviewed; photos |

## 4. Network Topology

```mermaid
flowchart LR
    HUB["ESP32 hub"] --> AP["Campus WiFi AP<br/>2.4 GHz — one subnet"]
    CAMB["ESP32-S3 CAM"] --> AP
    AP --> SRV["Server<br/>uvicorn :8000<br/>DHCP-reserved"]
    AP --> SSUB["SSU browsers<br/>LAN / campus network"]
```

- All three WiFi actors sit on one subnet so the browser→CAM frame poll (I5) works without a relay.
- DHCP reservations for hub + CAM + server — static addressing makes `CAM_IP` in firmware and the stream URL in the dashboard stable forever.
- Server can live on a laptop (POC), a campus server, or a small VPS; only requirement is LAN reachability from the pole for photo fetch, and campus reachability for the dashboard.

## 5. Failure Modes & Degradation

| Failure | Immediate effect | System behavior |
|---|---|---|
| WiFi down at pole | upload fails | photos still saved to CAM microSD; hub retries next event; card reconciled at maintenance |
| CAM reboot (heap) | beam #2 snapshot missed (and the close-time fallback) | hub logs incident with `confirmed` but no photo; microSD keeps prior photos; CAM auto-recovers ~60 s |
| Server down | POST fails | same as WiFi-down: evidence on microSD, dashboard obviously dark |
| Beam #1 mis-aimed (far post knocked) | confirmed=false always | incidents still log (radar-only); flagged in dashboard for review |
| Beam #2 mis-aimed (far post knocked) | CAM never self-triggers | hub's `/capture` falls back to a live grab — same behavior as the old single-beam design, never worse |
| Either far-post supply dead | one TX dark | other beam + radar unaffected (four isolated supplies — no cascade); dead beam detected in maintenance round via its boot-time state print |
| Radar phantom (branch/banners) | false kph ≥ 5 | beams stay intact → confirmed=false → filtered by SSU |
| Photo too dark (night) | OCR fails | plate_text stays NULL; nightly OCR retry; long-term fix is lighting |

**Design principle:** no single failure loses evidence — the CAM's microSD is the always-write copy, the cloud is the convenient copy.

## 6. Deployment Topology (POC → production path)

```mermaid
flowchart LR
    POC["POC / evaluation<br/>one laptop: FastAPI + SQLite + dashboard<br/>both boards on bench WiFi"] --> PILOT["Pilot — one lane<br/>campus server or mini-PC in guard post<br/>one pole unit + self-powered far post"] --> SCALE["Scale — multi-lane<br/>per-lane pole units → one server<br/>SQLite → PostgreSQL · uploads/ → object storage"]
```

The architecture doesn't change between stages — only where the server process runs and which database driver it opens.

---

Interfaces in detail: [BACKEND.md](BACKEND.md) §2 · Firmware contracts: [FIRMWARE.md](FIRMWARE.md) · Signals: [BLOCK-DIAGRAM.md](BLOCK-DIAGRAM.md) · Logic: [FLOWCHART.md](FLOWCHART.md)

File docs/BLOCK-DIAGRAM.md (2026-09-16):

# Block Diagram

Hardware blocks and the signals that connect them — the physical view of SafeWay. Diagrams are **Mermaid** and render natively on GitHub.

---

## 1. Overall System Block Diagram

```mermaid
flowchart TB
    subgraph FAR["FAR POST — self-powered"]
        TX1["KY-008 laser TX #1<br/>supply #1"]
        TX2["KY-008 laser TX #2<br/>supply #2"]
    end

    subgraph POLE["HUB POLE — weatherproof enclosure"]
        RX1["Laser receiver #1<br/>comparator behind clear window"]
        RX2["Laser receiver #2<br/>behind its own window"]
        RADAR["CDM324 24 GHz<br/>Doppler radar"]
        BUZZ["Active buzzer 5 V"]
        HUB["ESP32 38-pin HUB<br/>pulse ISR — GPIO 34<br/>beam #1 ISR + 50 ms debounce — GPIO 25<br/>buzzer — GPIO 27<br/>event logic · Hz→km/h · WiFi"]
        CAM["ESP32-S3 WROOM CAM (OV5640)<br/>beam #2 ISR — GPIO 21 → self-triggered snapshot<br/>cached plate frame on /capture<br/>/stream polled live frame<br/>microSD 16 GB failover"]
        P3["Supply #3 · 5 V 2 A"]
        P4["Supply #4 · 5 V 2 A"]
    end

    subgraph SRV["SERVER — one process"]
        API["FastAPI + uvicorn :8000<br/>SQLite safeway.db · uploads/<br/>plate recognition (OpenCV + Tesseract)"]
    end

    subgraph SSU["SSU BROWSER"]
        DASH["Monitoring dashboard<br/>violation table · photo pane · live feed"]
    end

    TX1 -- "650 nm dot #1 across the lane" --> RX1
    TX2 -- "650 nm dot #2 across the lane (offset)" --> RX2
    RX1 -- "DO → GPIO 25" --> HUB
    RX2 -- "DO → GPIO 21" --> CAM
    RADAR -- "OUT → GPIO 34" --> HUB
    HUB -- "GPIO 27" --> BUZZ
    HUB -- "① GET /capture at beam-break — receives CAM's cached beam-moment frame" --> CAM
    HUB -- "② POST /api/incidents — JSON" --> API
    CAM -. "③ polled frame — img tag, ~1/s" .-> DASH
    API -- "④ GET incidents + photos" --> DASH
    P3 -.-> HUB
    P3 -.-> RADAR
    P3 -.-> RX1
    P4 -.-> CAM
    P4 -.-> RX2
```

**Legend:** solid arrows = data · dotted arrows = power · numbered flows:

- ① at beam-break, the hub pulls the evidence photo from the CAM (WiFi) — what it receives is the **beam-moment frame the CAM already captured itself** (vehicle at the pole, plate in frame)
- ② hub uploads the incident JSON (WiFi)
- ③ dashboard live feed goes browser→CAM directly (LAN) — no server relay
- ④ dashboard reads the API
- **No cable crosses the road** — TX #1 and TX #2 each run on their own far-post supply; the two poles talk over WiFi only

---

## 2. Power Distribution — four independent supplies

```mermaid
flowchart LR
    S1["Supply #1 · far post<br/>5 V ≥1 A + 18650 UPS<br/>(HARDWARE §5.5)"] -.-> TX1V["KY-008 TX #1<br/>under 30 mA"]
    S2["Supply #2 · far post<br/>5 V ≥1 A + 18650 UPS<br/>(HARDWARE §5.5)"] -.-> TX2V["KY-008 TX #2<br/>under 30 mA"]
    S3["Supply #3 · hub pole<br/>5 V 2 A + 18650 UPS<br/>(HARDWARE §5.5)"] -.-> HUBV["38-pin hub VIN<br/>board + WiFi bursts"]
    S3 -.-> RRV["CDM324 VCC<br/>~30–60 mA"]
    S3 -.-> LRV["Laser receiver #1 VCC<br/>~10 mA"]
    S4["Supply #4 · hub pole<br/>5 V 2 A + 18650 UPS<br/>(HARDWARE §5.5)"] -.-> CAMV["ESP32-S3 WROOM CAM 5 V<br/>board + OV5640 + WiFi + SD"]
    S4 -.-> LRV2["Laser receiver #2 VCC<br/>~10 mA"]
```

- Four supplies, zero shared rails ⇒ a camera reboot can never brown-out the radar mid-measurement; a dead far-post supply can never dim the other beam; a hub buzzer/WiFi burst can never ripple the CAM's rail.
- **Every supply carries its own 18650 UPS branch** (TP4056 → cell → MT3608 @ 5.0 V, mains behind an SS34) — a mains outage bumps every rail, including both far-post lasers, for 4 h. No fuse, no paralleling: one protected cell per rail.
- **No cable crosses the road** — each far-post TX is self-powered (compact USB charger inside its housing).
- One rail cap recommended on each board's supply when bench-testing from a single source.

---

## 3. Signal Chain Summary

| Signal | Source → Destination | Conditioning | Meaning |
|---|---|---|---|
| Doppler IF pulses | CDM324 OUT → LM358 → GPIO 34 | two-stage ×101 amplifier, 2.5 V-biased ([HARDWARE §4](HARDWARE.md#4-lm358-signal-conditioner-radar-chain)) — direct only if the §3 scope check shows a healthy swing | pulse rate = 44.7 Hz per km/h |
| Beam #1 level | laser RX #1 DO → GPIO 25 | internal pull-up; divider only if DO swings to 5 V | LOW/HIGH = beam intact/broken (`BEAM_BREAKS_LOW`) |
| Beam #2 level | laser RX #2 DO → GPIO 21 (CAM) | `INPUT_PULLUP`; divider **mandatory** if DO >3.3 V (S3 not 5 V tolerant) | drives the CAM's self-triggered snapshot (`CAM_BEAM_BREAKS_LOW`) |
| Beam #1/#2 (optical) | KY-008 TX #1/#2 → receiver windows | 650 nm dots across the lane, offset a few cm | blocked = solid object crossing |
| Alert | GPIO 27 → buzzer | direct (active 5V module) | HIGH while kph over limit |
| Evidence | CAM self-trigger + `/capture` → hub (WiFi) | beam #2 break → cached PSRAM frame; hub fetches on beam #1 break | plate-frame JPEG (vehicle at the pole) + microSD save |
| Incident | hub → API (WiFi) | JSON POST | speed, limit, doppler_hz, confirmed, photo |

---

Electrical details: [HARDWARE.md](HARDWARE.md) · pin map & wiring tables · full schematic: [wiring/circuit_image.png](../wiring/circuit_image.png)
Data flow logic: [FLOWCHART.md](FLOWCHART.md) · Layers & interfaces: [SYSTEM-ARCHITECTURE.md](SYSTEM-ARCHITECTURE.md)

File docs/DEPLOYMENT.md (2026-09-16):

# Deployment Guide — Site Installation

Taking the validated prototype from the bench to the pilot road: site survey, physical install, connectivity, SSU handover, and maintenance. (PPDIOO **Operate → Optimize**.)

**Estimated time:** half-day install + half-day handover

---

## 1. Site Survey (pick the road segment)

Criteria for the pilot lane — walk candidates with SSU:

| Factor | Requirement | Why |
|---|---|---|
| Lane length | ≥ 30 m straight visible from pole position | Radar needs 10–30 m of approach to build the peak reading |
| Speed history | Known overspeeding complaints | Matches the study's purpose |
| Power | Outlets within extension reach | Four supplies: two 5V 2A adapters at the hub pole + two compact USB chargers at the far post (one extension cord reaches both posts if the far side has no outlet) |
| WiFi | RSSI ≥ −70 dBm at the pole (test with a phone at mount height) | Both boards upload reliability |
| Mounting | One rigid post/pole/wall corner at lane edge, box at ~1–1.5 m | Single-pole unit; camera + radar aim |
| Background | No large moving objects in the radar cone: trees, banners, AC condensers, parked cars | Phantom triggers |
| Safety | Lane remains passable; nothing overhanging traffic | Duh |
| SSU visibility | Near a guard post / patrol route | Physical deterrence + maintenance access |

**Record on the survey sheet:** pole GPS/ID, lane width at the crossing point (sets the far-post distance), measured radar mount angle (sets `COSINE_ANGLE_DEG`), far-post footing option (existing post/tree/fence vs. new PVC), power outlet locations both sides of the lane, WiFi SSID + signal, photo of the site from both directions.

## 2. Pre-Install Checklist

- [ ] Bench + calibration tests passed ([TESTING.md](TESTING.md))
- [ ] `BEAM_BREAKS_LOW` polarity verified on the bench (receiver DO level, beam intact vs blocked)
- [ ] `COSINE_ANGLE_DEG` set from the *site* mount angle (or kept 0 if aimed near-parallel)
- [ ] WiFi credentials for the campus SSID configured (2.4 GHz!)
- [ ] `API_URL` points at the production server; `CAM_IP` matches the CAM's **DHCP reservation**
- [ ] **DHCP reservation set on the campus router** for both boards (hub + CAM) — static IPs make everything findable forever
- [ ] Enclosure sealed, desiccant fresh, camera window clean, radar face within 2 cm of the ABS wall
- [ ] microSD formatted, inserted, tested
- [ ] Spare adapter, zip ties, and screwdriver in the kit box
- [ ] SSU informed of install date/time (traffic marshalling for 1–2 h)

## 3. Physical Install

### 3.1 The pole unit (everything's in one box now)

1. Mount the enclosure on the pole at **1–1.5 m**, camera facing the trigger zone at plate height.
2. **Radar aim:** beam along the traffic direction, **≤15° off the lane axis** — the sweet spot is 10–15°. A protractor app on your phone against the box edge works.
3. **Break-beam alignment (one-time, two-person, ×2 pairs):** aim each far-post KY-008 dot at its receiver window — TX #1 → receiver #1 (hub serial `BEAM` state), TX #2 → receiver #2 (CAM serial `BEAM2` state). Nudge each far post until both beams read **intact**. Re-check after typhoons (a knocked far post is the #1 beam failure mode).
4. Power: hub-pole adapters inside a small weatherproof junction box at the outlet; DC runs up to the enclosure; drip loops at every entry. Far post: each TX's compact USB charger lives inside its own small housing — no mains run crosses the road.
5. UV-rated cable ties on all runs; check nothing metallic sits between radar face and road.

### 3.2 Verify, then leave

1. Power up → serial (laptop at the pole) shows WiFi + `SafeWay HUB ready` + `CAM ready`.
2. Browser check: `/stream` returns a fresh frame from a phone on campus WiFi.
3. Marshal 3–5 drive-pasts at mixed speeds → all appear on dashboard with photos + live feed works.
4. Verify `confirmed=✓` on at least one drive-past (break-beam agreeing with radar).
5. Physically tug-test every mount and cable.
6. Photograph the finished install for the paper's Figure 8 (prototype deployed).

## 4. Connectivity Failover Notes

- **If site WiFi is flaky:** photos still save to the CAM's microSD — the incident isn't lost, just late to the cloud. The hub retries on next event; during maintenance, pull the card to reconcile ([TESTING.md §4](TESTING.md#4-reliability--soak-test) taught the CAM crash drill — same recovery here).
- **SSU should know: dashboard blank ≠ system dead.** Check the buzzer on a drive-past; if it sounds, the hub is alive and photos are on SD.
- **CAM-only failure:** live feed grays out (`cam-status` shows offline), but speed logging continues — the hub just can't fetch a photo. Fix on the next maintenance window.
- **Hub-only failure:** live feed keeps working (CAM serves frames independently) — SSU sees the lane but no new records. Buzzer silent on drive-pasts = hub is the issue.

## 5. SSU Handover & Training (Operate)

Half-day session with the personnel who will actually use it:

1. **Dashboard walkthrough** (30 min): live feed pane, filter new, view photo, filter confirmed-only, mark reviewed, export the incident log (paper trail for reports).
2. **Daily routine** (15 min): morning check of overnight violations; reconcile against guard log; glance at the live feed.
3. **What the buzzer means**: overspeed event in progress — no action needed at the device.
4. **Limits of the POC**: single lane, one pole, speed events only — it supplements, not replaces, patrols.
5. **Reporting faults**: single point of contact + the symptoms table below.
6. Sign-off sheet: names, date, version of guide handed over.

Leave printed copies: this guide's §5–7, the dashboard URL, and the fault table.

## 6. Maintenance Schedule (Optimize)

| Cadence | Task |
|---|---|
| Weekly | Pull CAM microSD (or spot check), verify photos exist for the week's dashboard records |
| Weekly | Visual: enclosure seals, cable ties, camera window |
| Monthly | Clean camera window + receiver window + radar-facing ABS wall (outside face); check desiccant |
| Monthly | Backup `safeway.db` + `uploads/` off the server |
| Quarterly | Re-run the 10-pass calibration ([TESTING.md §2](TESTING.md#2-speed-calibration-the-critical-test)) at the site; re-check radar aim angle + re-torque mounts |
| Quarterly | Check 18650 UPS cells ([HARDWARE.md §5.5](HARDWARE.md#55-battery-backup-ups-option--one-18650-per-supply)): pull-the-plug test, cell voltage ≥ 3.9 V under load, no holder corrosion |
| Yearly | Replace 18650 cells (~800 cycles rated); plan adapter/cable replacement every 2 typhoon seasons |

### Typhoon season prep

Take-down criteria (SSU decides): storm signal #2 or expected gusts > 60 km/h → unpower, unbolt the box, bring it indoors. One box, two adapters, four screws — **10-minute teardown** (unplug the two far-post USB chargers and cap the TX housings; nothing crosses the road, so there is no cable run to coil — the far-post TXs + chargers come down as two self-contained units).

## 7. Fault Symptoms → Actions (leave with SSU)

| Symptom | First response | If unresolved |
|---|---|---|
| Buzzer silent on a fast vehicle | Radar face blocked? (dirt, stickers, bird nest on the box) | Clean wall; IT ticket — check hub serial |
| Live feed grayed out | CAM rebooted — give it 60 s | IT ticket — power-cycle CAM adapter |
| Dashboard no new records, buzzer works | WiFi down at the pole (phone test) | IT ticket — network team |
| Records but `confirmed` always — | Receiver #1 window dirty / far post knocked (beam #1 permanently broken or mis-aimed) | Clean window; re-align TX #1 (§3.1); check `BEAM_BREAKS_LOW` polarity |
| Photos never beam-timed (stale angles) | Beam #2 mis-aimed — CAM never self-triggers | Re-align TX #2 (CAM serial `BEAM2`); check `CAM_BEAM_BREAKS_LOW` polarity; verify far-post supply #2 |
| Photos dark/blurry at night | Confirm lane light is on | Add lighting (capstone Optimize phase) |
| Plate column empty | Photo angle changed? | Re-run camera aim (§3.1) — OCR retries nightly |
| Speeds look wrong (low) | Pole knocked to a steeper angle? | Re-measure angle; update `COSINE_ANGLE_DEG` |
| Either board off entirely | Check its supply at the outlet | Swap supply (spare adapter in kit) |
| One beam dark, other fine | That far-post USB charger failed | Swap charger (spare in kit); re-align dot |
| Phantom events, no cars visible | Something moving in the radar cone? | Clear the corridor; raise `MIN_SPEED_KPH` |

## 8. Data & Privacy Notes

- Captured photos contain plates + occasionally people. Dashboard access = SSU authorized staff only; server stays on campus network.
- The **live feed** shows the public lane continuously — same visibility as standing there; still, restrict dashboard access to authorized SSU accounts and keep the server off the public internet.
- Set a retention rule with SSU (suggest: 90 days for reviewed incidents, then archive/purge) — also keeps SQLite lean.
- The capstone disclaimer permits sharing the *system and code* with acknowledgment; captured *data* belongs to the client institution's policy.

---

Build chain complete: [BOM](BOM.md) → [HARDWARE](HARDWARE.md) → [FIRMWARE](FIRMWARE.md) → [BACKEND](BACKEND.md) → [TESTING](TESTING.md) → **DEPLOY**

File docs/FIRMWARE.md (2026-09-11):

# Firmware Guide — Two-Board Architecture

Two independent sketches, one per board. Each flashes over its own USB port.

**Estimated time:** 1.5–2.5 hours (IDE setup + both flashes)

| Sketch | Board | Job |
|---|---|---|
| `safeway-cam` | ESP32-S3 WROOM N16R8 CAM | photo server: `/capture` (cached beam-moment JPEG) + `/stream` (polled live frame) + SD backup + **beam #2 self-trigger on GPIO 21** |
| `safeway-hub` | ESP32 38-pin | Doppler speed + break-beam #1 confirm + buzzer + beam-break photo fetch + upload to API |

---

## 1. Arduino IDE Setup (once, both boards use it)

1. Install **Arduino IDE 2.x** — https://www.arduino.cc/en/software
2. Add the ESP32 board package:
   - *File → Preferences → Additional boards manager URLs*:
     ```
     https://raw.githubusercontent.com/espressif/arduino-esp32/gh-pages/package_esp32_index.json
     ```
   - *Tools → Board → Boards Manager* → search **esp32** → install **esp32 by Espressif Systems** (v2.x+)
3. Drivers (all usually automatic on Windows 10/11):
   - **38-pin board:** CP2102 driver — https://www.silabs.com/developer-tools/usb-to-uart-bridge-vcp-drivers
   - **CAM board:** CH343P USB-serial driver — https://www.wch-ic.com/downloads (only if the port doesn't appear; the board's second Type-C is native USB-OTG and needs no driver)
4. No extra libraries needed — WiFi, HTTPClient, base64, SD_MMC ship with the ESP32 core.

---

## 2. Sketch 1 — `safeway-cam` (camera board)

Serves two still endpoints and a status page; watches **break-beam #2** on GPIO 21 — the instant the beam breaks, it grabs the plate frame itself (no waiting for the hub's HTTP request), saves it to microSD, and **caches it in PSRAM**; the hub's `/capture` fetch then returns the cached beam-moment frame instead of a fresh (possibly late) grab. Live-view frames never touch the card.

```cpp
/* safeway-cam — ESP32-S3 WROOM N16R8 CAM board (DevKit N16R8 CAM family)
   Endpoints:  /capture  -> cached beam-moment JPEG if fresh, else live grab
                         (beam-moment captures also saved to microSD)
               /stream   -> single JPEG frame, no SD write (dashboard polls ~1/s)
               /         -> tiny status page, no frame grab
   Beam #2:    receiver #2 DO -> GPIO 21 (CAM_BEAM_BREAKS_LOW polarity)
               break -> immediate self-triggered snapshot, cached + SD saved  */

#include "esp_camera.h"
#include <WiFi.h>
#include <SD_MMC.h>

// ---------- CONFIG ----------
const char* WIFI_SSID = "Campus-WiFi";     // 2.4 GHz network!
const char* WIFI_PASS = "********";
const bool  CAM_BEAM_BREAKS_LOW = true;    // true: DO LOW = beam intact (most modules)
                                           // set from the bench polarity check (HARDWARE §5.2)
const uint32_t BEAM2_FRESH_MS = 8000;     // cached beam photo served this long after the break
// ----------------------------

#define PIN_BEAM2 21                        // laser receiver #2 DO (no camera/SD/strap role)

// ESP32-S3 DevKit N16R8 CAM pin model — verified from the board's pinout
// diagram, cross-checked against the xiaozhi-esp32 bread-compact-wifi-s3cam
// board config (14/14 pins match). PWDN/RESET are not wired on this board.
// Confirm against the printed pinout card on first boot.
#define PWDN_GPIO_NUM  -1
#define RESET_GPIO_NUM -1
#define XCLK_GPIO_NUM  15
#define SIOD_GPIO_NUM   4    // SCCB SDA
#define SIOC_GPIO_NUM   5    // SCCB SCL
#define Y9_GPIO_NUM    16    // D7
#define Y8_GPIO_NUM    17    // D6
#define Y7_GPIO_NUM    18    // D5
#define Y6_GPIO_NUM    12    // D4
#define Y5_GPIO_NUM    10    // D3
#define Y4_GPIO_NUM     8    // D2
#define Y3_GPIO_NUM     9    // D1
#define Y2_GPIO_NUM    11    // D0
#define VSYNC_GPIO_NUM  6
#define HREF_GPIO_NUM   7
#define PCLK_GPIO_NUM  13

WiFiServer server(80);
int snapCount = 0;

// --- break-beam #2: self-triggered snapshot ---
volatile uint32_t beam2EdgeMs = 0;
volatile bool beam2SnapReq = false;         // loop: beam broke -> grab the plate frame NOW
IRAM_ATTR void onBeam2Edge() {
  uint32_t now = millis();
  if (now - beam2EdgeMs < 50) return;      // debounce: ignore edges <50 ms apart
  beam2EdgeMs = now;
  bool level = digitalRead(PIN_BEAM2);
  bool broken = CAM_BEAM_BREAKS_LOW ? (level == HIGH) : (level == LOW);
  if (broken) beam2SnapReq = true;         // vehicle in frame RIGHT NOW
}

uint8_t* snapBuf = nullptr;                // cached beam-moment JPEG (PSRAM)
size_t   snapLen = 0;
uint32_t snapMs   = 0;                      // when it was captured

void beamSnapshot() {                      // called from loop() on the flag
  camera_fb_t* fb = esp_camera_fb_get();
  if (!fb) return;
  if (snapBuf) free(snapBuf);              // replace stale cache (PSRAM — no heap frag)
  snapLen = fb->len;
  snapBuf = (uint8_t*)ps_malloc(snapLen);
  if (snapBuf) memcpy(snapBuf, fb->buf, snapLen);
  snapMs = millis();
  // SD save: the beam-moment capture IS the violation photo
  String path = "/sw_" + String(millis()) + "_" + String(snapCount++) + ".jpg";
  File f = SD_MMC.open(path, FILE_WRITE);
  if (f) { f.write(fb->buf, fb->len); f.close(); }
  esp_camera_fb_return(fb);
  Serial.println("BEAM2 SNAP -> SD ok");
}

bool camInit() {
  camera_config_t cc = {};
  cc.ledc_channel = LEDC_CHANNEL_0;
  cc.ledc_timer   = LEDC_TIMER_0;
  cc.pin_pwdn     = PWDN_GPIO_NUM;  cc.pin_reset = RESET_GPIO_NUM;
  cc.pin_xclk     = XCLK_GPIO_NUM;  cc.pin_sccb_sda = SIOD_GPIO_NUM;
  cc.pin_sccb_scl = SIOC_GPIO_NUM;  cc.pin_vsync = VSYNC_GPIO_NUM;
  cc.pin_href     = HREF_GPIO_NUM;  cc.pin_pclk  = PCLK_GPIO_NUM;
  cc.pin_d0 = Y2_GPIO_NUM; cc.pin_d1 = Y3_GPIO_NUM;
  cc.pin_d2 = Y4_GPIO_NUM; cc.pin_d3 = Y5_GPIO_NUM;
  cc.pin_d4 = Y6_GPIO_NUM; cc.pin_d5 = Y7_GPIO_NUM;
  cc.pin_d6 = Y8_GPIO_NUM; cc.pin_d7 = Y9_GPIO_NUM;
  cc.xclk_freq_hz = 20000000;
  cc.pixel_format = PIXFORMAT_JPEG;
  cc.frame_size   = FRAMESIZE_SVGA;      // 800x600 — plate-readable, small upload
  cc.jpeg_quality = 12;                   // lower = better, heavier
  cc.fb_count     = 2;                    // grab latest while serving the previous
  cc.fb_location  = CAMERA_FB_IN_PSRAM;   // 8 MB octal PSRAM — internal heap stays free for WiFi
  cc.grab_mode    = CAMERA_GRAB_LATEST;  // OV5640 headroom: FRAMESIZE_HD works too —
                                         // only if the hub heap tolerates the bigger base64 upload (§5)
  return esp_camera_init(&cc) == ESP_OK;
}

void sdSaveRemovalMarker() {}  // (removed — the beam-moment capture writes its own SD copy inside beamSnapshot())

void setup() {
  Serial.begin(115200);
  if (!camInit()) { Serial.println("CAMERA FAIL"); while (true) delay(100); }
  SD_MMC.setPins(39, 38, 40);               // S3 GPIO-matrix SD: CLK=39, CMD=38, D0=40
  SD_MMC.begin("/sdcard", true);            // 1-bit mode: leaves GPIOs free
  pinMode(PIN_BEAM2, INPUT_PULLUP);         // receiver #2 comparator DO (GPIO 21 has real pull-ups)
  attachInterrupt(digitalPinToInterrupt(PIN_BEAM2), onBeam2Edge, CHANGE);
  WiFi.begin(WIFI_SSID, WIFI_PASS);
  while (WiFi.status() != WL_CONNECTED) { delay(200); Serial.print("."); }
  Serial.println("\nCAM ready at http://" + WiFi.localIP().toString());
  server.begin();
}

void loop() {
  // Beam #2 fast path runs on every pass — the snapshot must land while the
  // vehicle is still in frame. Takes ~200-400 ms (grab + SD write), then the
  // server is free again.
  if (beam2SnapReq) { beam2SnapReq = false; beamSnapshot(); }

  // One connection at a time, but every request now finishes in well under a
  // second — so the hub's /capture is never stuck behind a long-running stream
  // (see the note below the sketch).
  WiFiClient c = server.available();
  if (!c) return;
  String req = c.readStringUntil('\r'); c.readStringUntil('\n');
  String path = req.substring(req.indexOf(' ') + 1);
  path = path.substring(0, path.indexOf(' '));
  if (path.indexOf('?') >= 0) path = path.substring(0, path.indexOf('?'));  // strip ?ts= cache-buster

  if (path == "/capture") {                              // violation photo
    bool fresh = snapBuf && (millis() - snapMs) < BEAM2_FRESH_MS;
    if (fresh) {                                         // serve the cached beam-moment frame —
      c.println("HTTP/1.1 200 OK\nContent-Type: image/jpeg"); // the vehicle AT the pole, plate in frame
      c.println("Content-Length: " + String(snapLen) + "\n");
      c.write(snapBuf, snapLen);
    } else {                                             // no fresh beam photo: live grab
      camera_fb_t* fb = esp_camera_fb_get();             // (fallback path — beam missed or CAM rebooted)
      if (!fb) { c.println("HTTP/1.1 503\nConnection: close\n"); c.stop(); return; }
      c.println("HTTP/1.1 200 OK\nContent-Type: image/jpeg");
      c.println("Content-Length: " + String(fb->len) + "\n");
      c.write(fb->buf, fb->len);
      esp_camera_fb_return(fb);
    }
  }
  else if (path == "/stream") {                          // single JPEG, no SD write
    camera_fb_t* fb = esp_camera_fb_get();
    if (!fb) { c.println("HTTP/1.1 503\nConnection: close\n"); c.stop(); return; }
    c.println("HTTP/1.1 200 OK\nContent-Type: image/jpeg");
    c.println("Content-Length: " + String(fb->len) + "\n");
    c.write(fb->buf, fb->len);
    esp_camera_fb_return(fb);
  }
  else if (path == "/") {                                 // status page — no frame grab
    c.println("HTTP/1.1 200 OK\nContent-Type: text/html\n\n"
              "<h2>SafeWay CAM</h2>/capture /stream OK");
  }
  else c.println("HTTP/1.1 404\nConnection: close\n");
  delay(5); c.stop();
}
```

**Why polled frames, not a true MJPEG stream?** A single-core ESP32 serving an endless multipart stream blocks its one HTTP server — while SSU watches live video, the hub's `/capture` would never get served, and violations would upload photoless. Serving one JPEG per request keeps every connection sub-second, so `/capture` is (virtually) always answerable; the dashboard gets a ~1 frame/s feed — plenty for lane monitoring — and the microSD only ever holds violation evidence, not live-view junk. True 10 fps streaming needs a dual-core split or RTSP — that's the upgrade path, not the POC.

**Why the beam lives on the CAM now (self-triggered snapshot):** with receiver #2 wired to the CAM's GPIO 21, the board that owns the camera also owns the trigger — the snapshot fires the instant the beam breaks with zero HTTP round-trip latency, while the vehicle is at the pole with the plate in frame. The hub still fetches via `GET /capture`, but what it receives is the **beam-moment cached frame**, not a "whenever the request happened to land" grab. The hub's own beam #1 (GPIO 25) keeps the event-confirm and event-close logic unchanged. Worst case (beam #2 mis-aimed, CAM rebooted): `/capture` falls back to a live grab — same behavior as the old design, never worse.

**Write down the IP it prints** (e.g. `192.168.1.45`) — the hub and the dashboard both need it. For production, give the CAM a **DHCP reservation** on the campus router so it never changes ([DEPLOYMENT.md §pre-install](DEPLOYMENT.md#2-pre-install-checklist)).

---

## 3. Sketch 2 — `safeway-hub` (38-pin sensor board)

The brain: counts Doppler pulses, converts Hz→km/h, confirms with the laser break-beam, buzzes on overspeed, snapshots the photo the instant the beam breaks, and uploads the incident when the lane clears. (Pin map vs the build: [full wiring diagram](../wiring/circuit_image.png).)

```cpp
/* safeway-hub — ESP32 38-pin (sensor hub)
   GPIO 34 = CDM324 OUT | GPIO 25 = laser receiver #1 DO (beam #1) | GPIO 27 = buzzer */

#include <WiFi.h>
#include <HTTPClient.h>
#include <base64.h>
#include <ArduinoJson.h>   // Arduino Library Manager: "ArduinoJson" by Benoit Blanchon

// ---------- CONFIG ----------
const char* WIFI_SSID = "Campus-WiFi";
const char* WIFI_PASS = "********";
const char* CAM_IP    = "192.168.1.45";     // from safeway-cam serial
const char* API_URL   = "http://192.168.1.10:8000/api/incidents";
const float HZ_PER_KPH = 44.7;              // CDM324 @ 24.125 GHz
                                            // (HB100 10.525 GHz variant: 19.49)
const float COSINE_ANGLE_DEG = 0.0;         // set if mounted off-axis (see HARDWARE §8)
const float SPEED_LIMIT_KPH  = 30.0;         // campus limit
const float MIN_SPEED_KPH   = 5.0;          // below this = noise, ignore
const bool  BEAM_BREAKS_LOW = true;         // true: DO LOW = beam intact (most modules)
                                            // set from the bench polarity check (HARDWARE §5.2)
// ----------------------------

#define PIN_RADAR   34
#define PIN_BEAM     25
#define PIN_BUZZER   27

volatile uint32_t pulses = 0;
IRAM_ATTR void onPulse() { pulses++; }

// --- laser break-beam: interrupt + software debounce ---
volatile uint32_t beamEdgeMs = 0;           // last accepted edge time (ms)
volatile bool beamBroken = false;           // true = vehicle (or object) blocking beam
volatile bool beamSnapReq = false;          // loop: beam broke -> snapshot the plate NOW
IRAM_ATTR void onBeamEdge() {
  uint32_t now = millis();
  if (now - beamEdgeMs < 50) return;        // debounce: ignore edges <50 ms apart
  beamEdgeMs = now;
  bool level = digitalRead(PIN_BEAM);        // read level at the edge
  // If DO LOW = beam intact (BEAM_BREAKS_LOW true), a rising edge = beam broken;
  // falling edge = beam restored.
  bool broken = BEAM_BREAKS_LOW ? (level == HIGH) : (level == LOW);
  beamBroken = broken;
  if (broken) beamSnapReq = true;           // fast path: plate is at the pole RIGHT NOW
}

float lastKph = 0, peakKph = 0, peakHz = 0;
uint32_t winStart = 0, lastActiveMs = 0;
bool inEvent = false, beamConfirmed = false;
String photoB64;                            // beam-break snapshot, reused across events
bool photoReady = false;                    // true once this event's photo is buffered

float kphFromHz(float hz) {
  float measured = hz / HZ_PER_KPH;
  if (COSINE_ANGLE_DEG > 0.1) measured /= cos(COSINE_ANGLE_DEG * PI / 180.0);
  return measured;
}

// Snapshot fetch: fires the instant the beam breaks -- the vehicle is AT the
// pole (1.5-3 m), plate in frame. Buffered as base64 in photoB64, which keeps
// its heap capacity across events (assignment never shrinks an Arduino
// String), so repeated snapshots do not fragment the heap.
bool fetchPhoto() {
  WiFiClient wc; HTTPClient http;
  http.begin(wc, String("http://") + CAM_IP + "/capture");
  http.setTimeout(4000);                    // dead CAM must not stall the loop
  bool ok = false;
  if (http.GET() == 200) {
    WiFiClient* s = http.getStreamPtr();
    int len = http.getSize();               // -1 if unknown
    photoB64 = "";                          // clear, keep capacity
    if (len > 0) photoB64.reserve((size_t)len * 4 / 3 + 8);
    uint8_t buf[512]; int got;
    while ((got = s->readBytes(buf, sizeof(buf))) > 0)
      photoB64 += base64::encode(buf, got);
    ok = photoB64.length() > 0;
  }
  http.end();
  return ok;
}

// POST the closed event. The photo is already buffered (beam-break snapshot,
// or the close-time fallback) -- one pre-reserved body, no inline fetch.
bool uploadIncident(float kph, float hz, bool confirmed) {
  String prefix = "{\"device_id\":\"safeway-01\",\"speed_kph\":" + String(kph, 1)
                + ",\"limit_kph\":" + String(SPEED_LIMIT_KPH, 0)
                + ",\"doppler_hz\":" + String(hz, 0)
                + ",\"confirmed\":" + (confirmed ? "true" : "false")
                + ",\"photo_b64\":\"";
  String body; body.reserve(prefix.length() + photoB64.length() + 3);
  body.concat(prefix); body.concat(photoB64); body.concat("\"}");
  WiFiClient wc; HTTPClient post;
  post.begin(wc, API_URL);
  post.addHeader("Content-Type", "application/json");
  post.setTimeout(8000);
  int rcode = post.POST(body);
  post.end();
  return rcode == 200 || rcode == 201;
}

void setup() {
  Serial.begin(115200);
  pinMode(PIN_RADAR, INPUT);
  pinMode(PIN_BEAM, INPUT_PULLUP);           // receiver comparator DO (GPIO 25 has pull-ups)
  pinMode(PIN_BUZZER, OUTPUT); digitalWrite(PIN_BUZZER, LOW);
  attachInterrupt(digitalPinToInterrupt(PIN_RADAR), onPulse, RISING);
  attachInterrupt(digitalPinToInterrupt(PIN_BEAM), onBeamEdge, CHANGE);
  // initial beam state (no edge has fired yet)
  delay(100);                                // let the receiver settle
  bool lvl = digitalRead(PIN_BEAM);
  beamBroken = BEAM_BREAKS_LOW ? (lvl == HIGH) : (lvl == LOW);
  WiFi.begin(WIFI_SSID, WIFI_PASS);
  while (WiFi.status() != WL_CONNECTED) { delay(200); Serial.print("."); }
  Serial.println("\nSafeWay HUB ready");
  Serial.printf("beam state at boot: %s\n", beamBroken ? "BROKEN (check alignment)" : "intact");
}

void loop() {
  // --- beam-break fast path: snapshot the plate the instant the beam breaks ---
  // The vehicle is AT the pole (1.5-3 m), plate in frame. Waiting for event
  // close instead would photograph the lane 15-35 m behind a 30 km/h car.
  noInterrupts(); bool snap = beamSnapReq; beamSnapReq = false; interrupts();
  if (snap && inEvent && !photoReady) {
    photoReady = fetchPhoto();
    Serial.println(photoReady ? "SNAPSHOT: ok" : "SNAPSHOT: failed (fallback at close)");
  }                                        // beam breaks outside an event: dropped

  // --- 300 ms Doppler window ---
  if (millis() - winStart < 300) return;
  uint32_t elapsed = millis() - winStart;
  noInterrupts(); uint32_t p = pulses; pulses = 0; interrupts();
  float hz  = (float)p * 1000.0f / elapsed;
  float kph = kphFromHz(hz);
  winStart = millis();

  if (WiFi.status() != WL_CONNECTED) WiFi.reconnect();

  // --- event state machine ---
  if (kph >= MIN_SPEED_KPH) {
    if (!inEvent) { inEvent = true; peakKph = 0; peakHz = 0; beamConfirmed = false;
                    photoReady = false; photoB64 = ""; }   // fresh event, fresh photo buffer
    if (kph > peakKph) { peakKph = kph; peakHz = hz; }
    lastActiveMs = millis();

    // laser break-beam: did a solid object cross the lane during the event?
    if (beamBroken) {
      beamConfirmed = true;
      Serial.println("BEAM BROKEN");
    }

    // buzzer: live warn while actively speeding
    digitalWrite(PIN_BUZZER, kph > SPEED_LIMIT_KPH ? HIGH : LOW);

    if (kph > SPEED_LIMIT_KPH) Serial.printf("ACTIVE %.1f km/h (%.0f Hz) beam=%s\n",
                                             kph, hz, beamBroken ? "broken" : "intact");
  }
  else if (inEvent) {
    digitalWrite(PIN_BUZZER, LOW);
    if (millis() - lastActiveMs > 1500) {   // lane clear -> close event
      inEvent = false;
      if (peakKph > SPEED_LIMIT_KPH) {       // VIOLATION
        Serial.printf("VIOLATION peak %.1f km/h | confirmed=%s\n",
                      peakKph, beamConfirmed ? "yes" : "no");
        // confirm beep
        for (int i = 0; i < 2; i++) { digitalWrite(PIN_BUZZER, HIGH); delay(120);
                                     digitalWrite(PIN_BUZZER, LOW);  delay(80); }
        // fallback: beam never broke this event (or the snapshot fetch failed) --
        // one more try; the car may already be past the pole (late frame)
        if (!photoReady) photoReady = fetchPhoto();
        // the handler below blocks ~1 s typical (photo already buffered):
        // discard pulses gathered during it so they don't dilute the next
        // window's Hz reading (see design notes)
        noInterrupts(); pulses = 0; interrupts();
        winStart = millis();
        bool ok = uploadIncident(peakKph, peakHz, beamConfirmed);
        Serial.println(ok ? "uploaded" : "UPLOAD FAILED (photo on CAM microSD)");
      } else {
        Serial.printf("pass: %.1f km/h (under limit)\n", peakKph);
      }
    }
  }
}
```

**Design notes:**

- **Peak-hold logic:** a car is visible to the radar for 2–3 s; each 300 ms window is a sample, and the event's recorded speed is the **peak** — matches how enforcement radar works and gives the fairest reading for a capstone evaluation.
- **Buzzer behavior:** sounds *while* the vehicle is actively over the limit (warns the driver in real time, per the paper's intent) + a confirmation double-beep when the violation is logged.
- **`confirmed` field:** the break-beam broke during the radar event → a solid object physically crossed the lane → guards against radar phantoms (branches, pedestrians). Dashboard shows it; SSU filters on it.
- **Fail-safe:** if the CAM or WiFi is down, the CAM's microSD still holds every photo (`/capture` handler saves before serving) — pull the card during maintenance ([DEPLOYMENT.md §4](DEPLOYMENT.md#4-connectivity-failover-notes)).
- **Beam-break snapshot (the plate fix):** the CAM self-triggers its capture the moment **beam #2** breaks — zero HTTP latency, the vehicle is at the pole (1.5–3 m), plate readable in frame — and caches it in PSRAM; the hub's fetch (fired on **beam #1**'s break flag, its own instant trigger) then pulls the cached beam-moment frame. The old close-time fetch photographed 15–35 m *behind* a 30 km/h car: at that distance a plate is ~12 px wide at SVGA — unreadable by OCR. Each beam ISR raises a flag; each board's loop services it within milliseconds.
- **Buffered upload:** the snapshot lives in one persistent `String photoB64` — cleared per event but its heap capacity is reused (assignment never shrinks it, so no fragmentation creep). The POST body is one pre-reserved allocation; peak hub heap ≈ 2× the photo (~120 KB at SVGA). SVGA stays the default — FRAMESIZE_HD is now tighter than the old single-copy design; heap-test before switching.
- **Radar-only fallback:** if beam #1 never broke (mis-aimed far post) or the snapshot fetch failed (CAM reboot), close-out retries once — a late frame, car possibly past the pole; still better than no photo, and the CAM's microSD keeps its copy either way.
- **Blocking close-out (known limit):** with the photo already buffered, the violation handler (double-beep + POST) blocks the loop only ~1 s typical; worst case with the CAM *and* server unreachable (two fetch timeouts + POST timeout) ~12 s. Pulses arriving during it are discarded, so a car entering mid-upload is measured from its next 300 ms window (peak-hold still catches its peak). A per-event async state machine is the upgrade path.
- **HB100 variant?** change one constant (`HZ_PER_KPH = 19.49`) — nothing else.

---

## 4. Flashing Procedure

### 4.1 Hub (38-pin board)
1. USB cable → Tools → Board: **ESP32 Dev Module**
2. Upload. Done — CP2102 handles reset/boot automatically.

### 4.2 CAM board (ESP32-S3 WROOM N16R8 CAM)
1. USB-C cable into **either port** — the USB-to-Serial (CH343P) port is the classic flash path; the USB-OTG port also works.
2. Tools → Board: **ESP32S3 Dev Module**, then set the rest:
   - **Flash Size: 16MB** · **PSRAM: OPI PSRAM** (N16R8 octal) · **USB Mode: Hardware CDC and JTAG**
   - **USB CDC On Boot: Enabled** (required when flashing/monitoring via the USB-OTG port)
3. Upload. The CH343P auto-download handles boot — no jumper needed. If the IDE can't find the board: hold **BOOT (IO0)**, click Upload, release when "Connecting..." appears.
4. Serial Monitor at 115200 → note the **CAM IP address**.

### 4.3 Bench smoke test (before mounting anything)
1. Hub serial shows `ACTIVE` lines when you wave a hand in front of the radar.
2. Browser on the same WiFi: `http://<cam-ip>/stream` → a frame appears (the dashboard's live pane re-polls it ~1/s).
3. Block/unblock **beam #1** with a book at ~1 m → hub prints `BEAM BROKEN`, boot message shows beam state. Block/unblock **beam #2** → CAM serial prints `BEAM2 SNAP → SD ok` each break. With a radar event active (wave over the radar), the beam-#2 block must also make the hub's photo fetch return the cached frame — hub prints `SNAPSHOT: ok` within ~1 s (bench test B10).
4. With the API running ([BACKEND.md](BACKEND.md)): drive a phone-flashlight "event" over the radar at speed → dashboard shows the incident with photo.

---

## 5. Tuning Constants

| Constant | Default | Effect |
|---|---|---|
| `SPEED_LIMIT_KPH` | 30 | violation threshold + buzzer trigger |
| `HZ_PER_KPH` | 44.7 | CDM324 physics — leave unless HB100 (19.49) |
| `COSINE_ANGLE_DEG` | 0 | set to measured mount angle to remove cosine under-read |
| `BEAM_BREAKS_LOW` | true | beam #1 polarity (hub) — set from the §5.2 bench check |
| `CAM_BEAM_BREAKS_LOW` | true | beam #2 polarity (CAM) — set from its own bench check (`true` = DO LOW means beam intact, most modules) |
| `BEAM2_FRESH_MS` | 8000 | how long the CAM serves its cached beam-moment photo after the break; longer = more tolerance for hub fetch delay, higher risk of serving a stale plate frame |
| `MIN_SPEED_KPH` | 5 | noise floor; raise if tree-wobble false-triggers |
| Window | 300 ms | shorter = faster response, noisier Hz estimate |
| Event close | 1500 ms | silence before closing an event (lane clear) |
| Violation upload | blocking ~1 s typical (photo buffered at beam-break; ~12 s worst case, CAM + API down) | pulses during the upload are discarded; async upload = upgrade path |

Tuning order for the field: `MIN_SPEED_KPH` first (kill phantom triggers), then `BEAM_BREAKS_LOW` from the bench polarity check, then `COSINE_ANGLE_DEG` from your measured install angle.

---

Next: the server that receives it → [BACKEND.md](BACKEND.md)

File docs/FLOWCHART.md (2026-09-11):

# Flowchart

Runtime behavior, decision by decision — the logic view of SafeWay, matching the actual hub sketch and API. Diagrams are **Mermaid** and render natively on GitHub.

---

## 1. Hub Main Loop — Speed Event Pipeline

A beam-break fast-path rides alongside the window loop on **each board**: the CAM self-triggers its snapshot the instant **beam #2** breaks (it owns both the camera and the trigger), and the hub fires its photo fetch the instant **beam #1** breaks — pulling the CAM's cached beam-moment frame. Every 300 ms window, the hub then samples, decides, and acts:

```mermaid
flowchart TB
    subgraph FAST["FAST PATH — every loop pass, before the window"]
        BB["beam #1 ISR raised the fetch flag"] --> ACT{"active event and<br/>no photo buffered yet ?"}
        ACT -- "yes" --> FETCH["GET /capture from CAM immediately —<br/>serves its cached beam-#2-moment frame<br/>base64 → heap buffer"]
        ACT -- "no — no radar event (pedestrian)<br/>or photo already held" --> DROP["drop the flag"]
    end

    W["300 ms window ends"] --> COUNT["read &amp; reset pulse count<br/>hz = pulses ÷ 0.3 s<br/>kph = hz ÷ 44.7 ÷ cos θ"]
    COUNT --> FLOOR{"kph ≥ 5.0 ?<br/>(MIN_SPEED_KPH noise floor)"}
    FLOOR -- "no" --> WIFI{"WiFi connected?"}
    WIFI -- "no" --> RC["WiFi.reconnect()"]
    RC --> W2["wait for next window"]
    WIFI -- "yes" --> W2
    FLOOR -- "yes" --> INEV{"inEvent ?"}
    INEV -- "no — start event" --> START["peak = 0 · beamConfirmed = false<br/>photoReady = false — fresh buffer"]
    INEV -- "yes" --> PEAK["peak-hold: kph &gt; peak →<br/>peak = kph · peakHz = hz"]
    START --> PEAK
    PEAK --> BEAM{"beamBroken ?<br/>(set by ISR)"}
    BEAM -- "yes" --> CONF["beamConfirmed = true"]
    BEAM -- "no" --> BZ["buzzer ON if kph &gt; SPEED_LIMIT_KPH"]
    CONF --> BZ
    BZ --> QUIET{"lane quiet &gt; 1500 ms<br/>while inEvent ?"}
    QUIET -- "no" --> W2
    QUIET -- "yes — close event" --> CLOSE["buzzer OFF · inEvent = false"]
    CLOSE --> OVER{"peak &gt; 30 km/h ?"}
    OVER -- "no" --> PASS["log pass — under limit"]
    OVER -- "yes — VIOLATION" --> BEEP["double-beep confirm"]
    BEEP --> FB{"photo buffered from<br/>the beam-break fast path ?"}
    FB -- "yes — plate frame" --> POST["POST /api/incidents<br/>speed · limit · doppler_hz · confirmed · photo_b64"]
    FB -- "no — beam never broke<br/>or the snapshot fetch failed" --> FBF["fallback: GET /capture at close —<br/>late frame, car may be past the pole"]
    FBF --> POST
    POST --> UP{"201 ?"}
    UP -- "yes" --> OK["uploaded"]
    UP -- "no" --> SDF["CAM microSD holds the photo"]
```

**Beam ISRs (fire any time, CHANGE):** beam #1 on hub GPIO 25 — edge → debounce (edges under 50 ms apart ignored) → read level → `BEAM_BREAKS_LOW` polarity → set/clear `beamBroken` → if broken, raise the fetch flag (the loop's fast path pulls the CAM's cached photo within milliseconds). Beam #2 on CAM GPIO 21 — same debounce/polarity logic with `CAM_BEAM_BREAKS_LOW` → if broken, the CAM loop runs `beamSnapshot()` itself: grab frame → cache in PSRAM → save to microSD (no HTTP round-trip involved at all).

## 2. Beam-Confirm vs Radar-Only Event

| Scenario | Radar | Beam #1 | Outcome |
|---|---|---|---|
| Car crosses | kph ≥ 5 | breaks | `confirmed: true` — strongest evidence |
| Branch sways in radar cone | kph ≥ 5 (maybe) | intact | `confirmed: false` — SSU filters it out |
| Car crosses, beam #1 mis-aimed | kph ≥ 5 | intact (fault) | `confirmed: false` — still logged, flagged for review |
| Pedestrian walks the beam | kph under 5 | breaks | no radar event — nothing logged |

(Beam #2 never gates `confirmed` — it only triggers the CAM's snapshot. A car crossing the lane breaks both beams in sequence: #2 fires the cached capture, #1 confirms the event.)

## 3. CAM Board Sketch Loop

```mermaid
flowchart TB
    BOOT["boot"] --> WIFJ["join WiFi"]
    WIFJ --> PRINT["print IP on serial"]
    PRINT --> LOOP2{"beam #2 broke ?<br/>(ISR flag)"}
    LOOP2 -- "yes" --> SNAP["beamSnapshot(): grab frame →<br/>cache in PSRAM → save JPEG to microSD"]
    SNAP --> SERVE
    LOOP2 -- "no" --> SERVE{"request ?"}
    SERVE -- "GET /capture" --> CAP{"cached beam photo<br/>fresher than 8 s ?"}
    CAP -- "yes" --> CACHED["serve cached beam-moment JPEG<br/>(plate frame, no fresh grab)"]
    CAP -- "no — beam missed / rebooted" --> LIVE["live frame grab → return JPEG<br/>(old on-demand behavior)"]
    SERVE -- "GET /stream" --> STR["single frame, no SD write<br/>(dashboard re-polls ~1/s)"]
    SERVE -- "GET /" --> STAT["cheap status page, no frame grab<br/>(cam-status just needs the HTTP 200)"]
```

The CAM's snapshot now fires at **beam #2's interrupt** — before any HTTP request exists. The hub's fetch arrives later and simply receives the cached plate frame (`BEAM2_FRESH_MS` window). Fallback: if no fresh cache exists, `/capture` grabs a live frame — never a hard failure.

## 4. Server-Side Incident Pipeline

```mermaid
flowchart TB
    REQ["POST /api/incidents"] --> VAL["validate (Pydantic) →<br/>decode photo_b64 →<br/>save uploads/sw_uuid.jpg"]
    VAL --> INS["INSERT row: speed · limit · doppler_hz<br/>confirmed · detected_at = now (server clock)"]
    INS --> PHOTO{"photo attached ?"}
    PHOTO -- "no" --> R201["return 201 {id, plate_text: null}"]
    PHOTO -- "yes" --> BG["background OCR thread<br/>(hub answered with 201 immediately)"]
    BG --> OCR["plate recognition:<br/>OpenCV preprocess (gray → bilateral → Canny)<br/>→ pytesseract PSM 7"]
    OCR --> UPD["UPDATE plate_text · plate_confidence"]
    UPD --> R201
```

- Recognition always runs in a background thread — the hub is answered 201 immediately; the row's plate fields fill in when OCR completes.
- Nightly OCR retry pass fills in plates for photos that were too dark.

## 5. Dashboard Session (SSU personnel)

```mermaid
flowchart LR
    OPEN["open /"] --> LIST["GET /api/incidents?reviewed=false"]
    LIST --> FILTER["filter: All / New only / Reviewed"]
    FILTER --> CONF["filter: confirmed only<br/>(radar + beam agree)"]
    CONF --> ROW["click row → GET /api/incidents/id/photo<br/>→ photo pane"]
    ROW --> LIVE["live lane: img polls http://CAM_IP/stream<br/>direct from CAM, ~1 frame/s"]
    LIVE --> REVIEW["review → PATCH /api/incidents/id<br/>{reviewed: 1}"]
    REVIEW --> CAMS["cam-status badge → GET /api/cam-status<br/>(server probes CAM)"]
```

---

Decision logic source: [FIRMWARE.md](FIRMWARE.md) §3 (hub sketch) · API behavior: [BACKEND.md](BACKEND.md) §2–4
Blocks & signals: [BLOCK-DIAGRAM.md](BLOCK-DIAGRAM.md) · Layers: [SYSTEM-ARCHITECTURE.md](SYSTEM-ARCHITECTURE.md)

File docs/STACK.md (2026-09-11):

# Stack

Everything SafeWay is built on — deliberately small, POC-friendly, and free.

---

## Firmware (ESP32 boards)

| Layer | Choice | Notes |
|---|---|---|
| IDE | **Arduino IDE 2.x** | One IDE for both boards — https://arduino.cc/en/software |
| Toolchain | **esp32 by Espressif Systems** (Arduino core v2.x+) | Board Manager URL: `https://raw.githubusercontent.com/espressif/arduino-esp32/gh-pages/package_esp32_index.json` |
| Board (hub) | **ESP32 Dev Module** (38-pin, CP2102 USB-UART) | Sensor hub sketch `safeway-hub` — radar pulse counting, break-beam ISR + beam-break photo snapshot, buzzer, upload |
| Board (camera) | **ESP32S3 Dev Module** (ESP32-S3 WROOM N16R8 CAM; CH343P USB-UART + native USB-OTG) | Camera sketch `safeway-cam` — `/capture` JPEG, `/stream` polled live frame, microSD backup. IDE: Flash 16MB · PSRAM: OPI PSRAM |
| Drivers | CP2102 (Silabs VCP) · CH343 (WCH) | Only if the COM port doesn't appear |
| Libraries | WiFi · HTTPClient · base64 · SD_MMC *(bundled with core)* + **ArduinoJson** (Benoit Blanchon, via Library Manager) | Nothing else to install |

## Backend (server)

| Layer | Choice | Why |
|---|---|---|
| Runtime | **Python 3.11** | |
| API framework | **FastAPI** | Async, auto OpenAPI docs at `/docs`, clean JSON/multipart photo handling |
| Server | **uvicorn** | `uvicorn main:app --host 0.0.0.0 --port 8000` — one process |
| Models | **Pydantic** | Request validation (ships with FastAPI) |
| Database | **SQLite** (file `safeway.db`) | Zero-config for POC; schema ports cleanly to **PostgreSQL** when volume grows |
| Photos | Local `uploads/` dir, path in DB | Swap for S3-compatible storage later |
| Plate recognition (default) | **pytesseract** + **OpenCV** (`opencv-python`) | Pure-Python: grayscale → bilateral filter → Canny → Tesseract PSM 7 |
| Plate recognition (upgrade) | **OpenALPR** agent | Only with a custom-trained PH region — upstream ships us/eu/au/br/in/kr/vn only (no `ph`), unmaintained since 2018 |
| Outbound HTTP | **requests** | CAM health check from the server |

## Frontend (dashboard + live feed)

| Layer | Choice | Why |
|---|---|---|
| Page | Server-served static HTML (`static/dashboard.html`) | No SPA framework, no build step — FastAPI serves it directly |
| Styling | **Tailwind CSS** (CDN) | Utility classes, zero toolchain |
| Logic | Vanilla **JS** (`fetch` → API) | List/filter/review incidents, photo popups |
| Live feed | `<img src="http://<cam-ip>/stream">` polled ~1/s | Browser pulls frames straight from the CAM over the LAN — no server relay |

## Hardware (context — see [BOM.md](BOM.md) & [HARDWARE.md](HARDWARE.md) · [wiring diagram](../wiring/circuit_image.png))

| Part | Role |
|---|---|
| CDM324 24 GHz Doppler radar | Speed measurement (Doppler IF = 44.7 Hz per km/h) |
| KY-008 laser pair #1 (TX far post + receiver on hub) | Break-beam presence confirmation across the lane |
| KY-008 laser pair #2 (TX far post + receiver on CAM, GPIO 21) | CAM self-triggered snapshot at the beam break |
| Active buzzer 5V | On-site overspeed alert (hub GPIO 27) |
| ESP32 38-pin dev board | Sensor hub (radar GPIO 34, beam #1 GPIO 25, buzzer GPIO 27) |
| ESP32-S3 WROOM N16R8 CAM (OV5640) | Photo evidence, live stream, microSD failover |

---

## Why this stack

- **One language on the server** — Python end-to-end: FastAPI routes, Pydantic models, OCR pipeline, dashboard serving.
- **One process to deploy** — uvicorn serves API + dashboard; SQLite is a file; no Docker required for the POC (add it later for the campus server).
- **No frontend build chain** — Tailwind via CDN + vanilla JS means nothing to compile, nothing to break during a capstone timeline.
- **Graceful upgrades** — SQLite → PostgreSQL, local `uploads/` → object storage, local OCR → cloud ANPR: each swap is isolated to one module.
- **All free & open-source** — total software cost ₱0; the budget lives in hardware (~₱2,328).

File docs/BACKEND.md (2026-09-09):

# Backend & Dashboard Guide — Cloud API

The server side of SafeWay: a REST API that receives violation incidents from the ESP32 hub, stores them, runs plate recognition, and serves the monitoring dashboard (with live lane feed) for SSU personnel.

**Estimated time:** 2–4 hours (first deploy)

---

## Stack (POC-friendly choices)

| Layer | Choice | Why |
|---|---|---|
| API | **FastAPI** (Python 3.11) | Async, automatic OpenAPI docs, multipart/JSON photo handling |
| Database | **SQLite** (file) → upgrade path: PostgreSQL | Zero-config for POC; schema ports cleanly |
| Photos | Local `uploads/` dir, path stored in DB | Simple; swap for S3-compatible storage later |
| Plate recognition | **OpenCV + pytesseract** (default) / OpenALPR (optional upgrade — upstream has no `ph` region) | Runs on captured photos (server-side, not on the ESP32) |
| Dashboard | FastAPI-served HTML + **Tailwind** + vanilla JS (fetch) | Single process to deploy; no separate frontend build |
| Live feed | `<img>` polling the CAM's `/stream` (~1 frame/s) | No server relay needed — browser pulls frames from the CAM over the same network |

Everything runs in one process you can host on a laptop, a campus server, or a small VPS.

---

## Repository Layout (suggested)

```
server/
├── main.py            # FastAPI app + routes + schema + db
├── plates.py          # plate recognition pipeline
├── requirements.txt
├── uploads/           # captured photos (jpg)
└── static/
    └── dashboard.html # SSU monitoring dashboard
```

---

## 1. Database Schema

```sql
CREATE TABLE IF NOT EXISTS incidents (
    id            INTEGER PRIMARY KEY AUTOINCREMENT,
    device_id     TEXT NOT NULL,
    detected_at   TEXT NOT NULL,          -- ISO 8601, server-received time
    speed_kph     REAL NOT NULL,          -- peak speed during the event
    limit_kph     REAL NOT NULL,
    doppler_hz    REAL,                   -- raw Doppler frequency at peak (audit/evidence)
    confirmed     INTEGER DEFAULT 0,      -- 1 = laser break-beam broke during the event (radar+beam agree)
    photo_path    TEXT,                   -- uploads/sw_1234.jpg
    plate_text    TEXT,                   -- from recognition (nullable until processed)
    plate_confidence REAL,
    reviewed      INTEGER DEFAULT 0       -- 0 = new, 1 = acknowledged by SSU
);

CREATE INDEX IF NOT EXISTS idx_incidents_time ON incidents(detected_at DESC);
```

- `doppler_hz` is stored so every speed reading is **auditable**: speed = doppler_hz ÷ 44.7 (÷ cosine correction). If a reading is ever disputed, the raw physics is in the record.
- `confirmed` is the two-sensor agreement flag (radar event + break-beam broken while the vehicle crossed). SSU can filter to confirmed-only for reports; unconfirmed events stay for analysis.
- `detected_at` is stamped **server-side** on receipt (the ESP32 has no reliable clock until you add NTP — see Tuning in [FIRMWARE.md](FIRMWARE.md)).

---

## 2. API Spec

Base URL: `http://<server>:8000` — docs auto-generated at `/docs` (Swagger UI).

### POST `/api/incidents` — receive a violation (called by the ESP32 hub)

Body: `application/json`

| Field | Type | Notes |
|---|---|---|
| `device_id` | string | e.g. `safeway-01` |
| `speed_kph` | float | peak speed, computed on the hub |
| `limit_kph` | float | campus limit |
| `doppler_hz` | float | raw Doppler frequency at peak |
| `confirmed` | bool | laser break-beam broke while the vehicle crossed the lane during the event |
| `photo_b64` | string | base64 JPEG (optional — the CAM's microSD has the backup) |

**201** → `{ "id": 42, "plate_text": null }`
Plate recognition runs in a **background thread** (the hub is answered immediately); the record's plate fields update when OCR completes.

### GET `/api/incidents?limit=50&reviewed=false&confirmed=true` — list for dashboard

Returns newest first: id, time, speed, doppler, confirmed, plate, photo URL, reviewed flag.

### GET `/api/incidents/{id}/photo` — serve the captured JPEG

### PATCH `/api/incidents/{id}` — mark reviewed / annotate

Body: `{ "reviewed": 1, "plate_text": "corrected plate" }` — for SSU corrections when OCR misreads.

### GET `/api/cam-status` — probe the camera board

Server-side `GET http://<cam-ip>/` with 3 s timeout → `{ "cam_online": true }`. Dashboard uses this to gray out the Live pane when the CAM reboots.

---

## 3. Server Implementation (main.py)

```python
import base64, os, sqlite3, threading, uuid
from datetime import datetime, timezone
import requests
from fastapi import FastAPI, HTTPException
from fastapi.responses import FileResponse, HTMLResponse
from pydantic import BaseModel

app = FastAPI(title="SafeWay API", version="0.2.0")
DB = "safeway.db"
UPLOADS = "uploads"
CAM_IP = "192.168.1.45"          # ESP32-S3 CAM address (DHCP-reserved)
os.makedirs(UPLOADS, exist_ok=True)

class Incident(BaseModel):
    device_id: str
    speed_kph: float
    limit_kph: float
    doppler_hz: float | None = None
    confirmed: bool = False
    photo_b64: str | None = None

def db() -> sqlite3.Connection:
    conn = sqlite3.connect(DB)
    conn.row_factory = sqlite3.Row
    return conn

SCHEMA = """
CREATE TABLE IF NOT EXISTS incidents (
    id            INTEGER PRIMARY KEY AUTOINCREMENT,
    device_id     TEXT NOT NULL,
    detected_at   TEXT NOT NULL,          -- ISO 8601, server-received time
    speed_kph     REAL NOT NULL,          -- peak speed during the event
    limit_kph     REAL NOT NULL,
    doppler_hz    REAL,                   -- raw Doppler frequency at peak (audit/evidence)
    confirmed     INTEGER DEFAULT 0,      -- 1 = laser break-beam broke during the event
    photo_path    TEXT,                   -- uploads/sw_1234.jpg
    plate_text    TEXT,                   -- from recognition (nullable until processed)
    plate_confidence REAL,
    reviewed      INTEGER DEFAULT 0       -- 0 = new, 1 = acknowledged by SSU
);
CREATE INDEX IF NOT EXISTS idx_incidents_time ON incidents(detected_at DESC);
"""

with db() as c:  # init schema on boot (same SQL as section 1)
    c.executescript(SCHEMA)

@app.post("/api/incidents", status_code=201)
def create_incident(inc: Incident):
    fname = None
    if inc.photo_b64:
        fname = f"{uuid.uuid4().hex}.jpg"
        with open(os.path.join(UPLOADS, fname), "wb") as f:
            f.write(base64.b64decode(inc.photo_b64))
    now = datetime.now(timezone.utc).isoformat()
    with db() as c:
        cur = c.execute(
            """INSERT INTO incidents
               (device_id, detected_at, speed_kph, limit_kph, doppler_hz,
                confirmed, photo_path)
               VALUES (?,?,?,?,?,?,?)""",
            (inc.device_id, now, inc.speed_kph, inc.limit_kph, inc.doppler_hz,
             int(inc.confirmed), fname))
        new_id = cur.lastrowid
    if fname:  # plate recognition in background (don't block the ESP32)
        threading.Thread(target=run_ocr, args=(new_id, fname), daemon=True).start()
    return {"id": new_id, "plate_text": None, "plate_confidence": None}

def run_ocr(inc_id: int, fname: str):
    from plates import recognize          # see section 4
    try:
        text, conf = recognize(os.path.join(UPLOADS, fname))
        with db() as c:
            c.execute("UPDATE incidents SET plate_text=?, plate_confidence=? WHERE id=?",
                      (text, conf, inc_id))
    except Exception as e:
        print("OCR failed:", e)

@app.get("/api/incidents")
def list_incidents(limit: int = 50, reviewed: bool | None = None,
                   confirmed: bool | None = None):
    q = ("SELECT id, device_id, detected_at, speed_kph, limit_kph, doppler_hz, "
         "confirmed, plate_text, plate_confidence, photo_path, reviewed FROM incidents")
    args = []
    where = []
    if reviewed is not None:
        where.append("reviewed=?"); args.append(int(reviewed))
    if confirmed is not None:
        where.append("confirmed=?"); args.append(int(confirmed))
    if where:
        q += " WHERE " + " AND ".join(where)
    q += " ORDER BY detected_at DESC LIMIT ?"; args.append(limit)
    with db() as c:
        return [dict(r) for r in c.execute(q, args).fetchall()]

@app.get("/api/incidents/{inc_id}/photo")
def photo(inc_id: int):
    with db() as c:
        row = c.execute("SELECT photo_path FROM incidents WHERE id=?", (inc_id,)).fetchone()
    if not row or not row["photo_path"]:
        raise HTTPException(404)
    return FileResponse(os.path.join(UPLOADS, row["photo_path"]))

@app.patch("/api/incidents/{inc_id}")
def update(inc_id: int, body: dict):
    fields, args = [], []
    for k in ("reviewed", "plate_text"):
        if k in body:
            fields.append(f"{k}=?"); args.append(body[k])
    if not fields: raise HTTPException(400, "nothing to update")
    args.append(inc_id)
    with db() as c:
        c.execute(f"UPDATE incidents SET {', '.join(fields)} WHERE id=?", args)
    return {"ok": True}

@app.get("/api/cam-status")
def cam_status():
    try:
        r = requests.get(f"http://{CAM_IP}/", timeout=3)
        return {"cam_online": r.status_code == 200}
    except Exception:
        return {"cam_online": False}

@app.get("/", response_class=HTMLResponse)
def dashboard():
    return open("static/dashboard.html", encoding="utf-8").read()
```

Run: `uvicorn main:app --host 0.0.0.0 --port 8000`

---

## 4. Plate Recognition (plates.py)

The runnable default is pure Python — OpenCV preprocess + Tesseract. OpenALPR is the optional upgrade path, not the default: its agent ships region configs for `us eu au br in kr vn` only — **there is no `ph` region** (`alpr -c ph` errors with "Invalid country") — and the project has been unmaintained since 2018. Real PH-plate ANPR means training a custom region or a cloud service; that's the production upgrade, not the POC.

```python
# Path A (default): pytesseract + OpenCV preprocess
#   pip install pytesseract opencv-python
import cv2, pytesseract, re

def recognize(path: str) -> tuple[str | None, float]:
    img = cv2.imread(path)
    gray = cv2.cvtColor(img, cv2.COLOR_BGR2GRAY)
    gray = cv2.bilateralFilter(gray, 9, 75, 75)
    edges = cv2.Canny(gray, 60, 180)
    text = pytesseract.image_to_string(
        gray, config="--psm 7 -c tessedit_char_whitelist=ABCDEFGHIJKLMNOPQRSTUVWXYZ0123456789"
    ).strip()
    m = re.search(r"[A-Z0-9]{5,8}", text.upper())
    return (m.group(0), 0.5) if m else (None, 0.0)
```

```python
# Path B (optional upgrade): OpenALPR agent — only if you train & install a
# PH region config first (upstream regions: us eu au br in kr vn — no 'ph').
import subprocess

def recognize(path: str) -> tuple[str | None, float]:
    out = subprocess.run(
        ["alpr", "-c", "ph", path],          # requires your own trained region
        capture_output=True, text=True, timeout=20
    ).stdout.strip().splitlines()
    if not out: return None, 0.0
    # first line:  -  ABC1234    91.3% confidence
    parts = out[0].split()
    return parts[1], float(parts[2].rstrip("%")) / 100.0
```

> PH plates: 3 letters + 4 digits (private) or LLL-DDDD variants (motor). The regex/whitelist handles both. Low light = garbage OCR — the fix is lighting, not code (see [FIRMWARE.md](FIRMWARE.md) tuning).

---

## 5. Monitoring Dashboard (static/dashboard.html)

Table of recent incidents + photo pane + **live lane feed** from the CAM + filter. Vanilla JS:

```html
<!doctype html>
<html lang="en">
<head>
  <meta charset="utf-8">
  <meta name="viewport" content="width=device-width, initial-scale=1">
  <title>SafeWay — SSU Monitoring Dashboard</title>
  <script src="https://cdn.tailwindcss.com"></script>
</head>
<body class="bg-slate-100 p-6">
  <h1 class="text-2xl font-bold mb-4">SafeWay Violations</h1>

  <div class="flex gap-3 mb-4">
    <select id="filter" class="border rounded p-2" onchange="load()">
      <option value="">All</option>
      <option value="false">New only</option>
      <option value="true">Reviewed</option>
    </select>
    <select id="conly" class="border rounded p-2" onchange="load()">
      <option value="">Radar + beam</option>
      <option value="true">Confirmed only</option>
    </select>
    <button onclick="load()" class="bg-blue-600 text-white rounded px-4 py-2">Refresh</button>
  </div>

  <div class="flex gap-6">
    <table id="tbl" class="bg-white rounded shadow text-sm w-2/3">
      <thead class="bg-slate-200"><tr>
        <th class="p-2 text-left">Time</th><th>Speed</th><th>Doppler</th>
        <th>Conf.</th><th>Plate</th><th>Status</th><th>Photo</th></tr></thead>
      <tbody></tbody>
    </table>
    <div class="w-1/3">
      <img id="live" class="rounded shadow w-full bg-slate-300 mb-2" alt="live">
      <div id="livecap" class="text-xs text-slate-500 mb-2">live lane feed</div>
      <img id="photo" class="rounded shadow w-full bg-slate-300" alt="capture">
    </div>
  </div>

<script>
const CAM_IP = "192.168.1.45";           // same as server config
const esc = s => (s ?? '—').replace(/[&<>"']/g,
  c => ({'&':'&amp;','<':'&lt;','>':'&gt;','"':'&quot;',"'":'&#39;'}[c]));
const live = document.getElementById('live');
function refreshLive() { live.src = `http://${CAM_IP}/stream?ts=${Date.now()}`; }  // cache-busted poll
refreshLive(); setInterval(refreshLive, 1200);   // pseudo-live ~1 frame/s

async function load() {
  const f = document.getElementById('filter').value;
  const c = document.getElementById('conly').value;
  let url = `/api/incidents?limit=50`;
  if (f) url += `&reviewed=${f}`;
  if (c) url += `&confirmed=${c}`;
  const rows = await (await fetch(url)).json();
  const tb = document.querySelector('#tbl tbody');
  tb.innerHTML = rows.map(i => `
    <tr class="border-t hover:bg-slate-50">
      <td class="p-2">${new Date(i.detected_at).toLocaleString()}</td>
      <td class="text-center font-bold ${i.speed_kph > i.limit_kph * 1.5 ? 'text-red-600' : ''}">
        ${i.speed_kph.toFixed(1)} km/h</td>
      <td class="text-center text-slate-500 font-mono">${i.doppler_hz ? Math.round(i.doppler_hz) + ' Hz' : '—'}</td>
      <td class="text-center">${i.confirmed ? '✓' : '—'}</td>
      <td class="text-center font-mono">${esc(i.plate_text)}</td>
      <td class="text-center">${i.reviewed ? 'Reviewed' : 'New'}</td>
      <td><button onclick="show(${i.id})" class="text-blue-600 underline">view</button></td>
    </tr>`).join('');
  // gray the live pane if the CAM is down
  const st = await (await fetch('/api/cam-status')).json();
  document.getElementById('livecap').textContent =
    st.cam_online ? 'live lane feed' : 'camera offline';
}
async function show(id) {
  document.getElementById('photo').src = `/api/incidents/${id}/photo`;
  await fetch(`/api/incidents/${id}`, {method: 'PATCH',
    headers: {'Content-Type': 'application/json'}, body: '{"reviewed": 1}'});
  load();
}
load(); setInterval(load, 15000);   // auto-refresh 15 s
</script>
</body>
</html>
```

SSU workflow: watch the **live pane** for context → violation rows arrive automatically → click *view* → photo opens, incident marked reviewed. The **Doppler Hz column + Conf. ✓** column give the evidence trail for reports.

> The dashboard must run on the **same network** as the CAM for the live feed (browser polls `http://<cam-ip>/stream` — one JPEG per request). Over VPN this works too; over public internet you'd need a relay — out of POC scope.

---

## 6. Deploy & Security Notes

- **Run behind the campus network/VPN** for the POC. Expose publicly only via a reverse proxy (nginx/caddy) with HTTPS.
- Add a shared API key later: `X-Device-Key` header checked in middleware (the ESP32 hub sets it with `http.addHeader`).
- SQLite is fine for POC volumes; move to PostgreSQL when > 1 device streams.
- Back up `safeway.db` + `uploads/` nightly (the CAM's microSD is the second copy of photos).
- **CORS**: if the dashboard is ever served from a different origin than the API, add `CORSMiddleware` — for POC it's same-origin, nothing to do.

---

Next: calibrate and evaluate → [TESTING.md](TESTING.md)

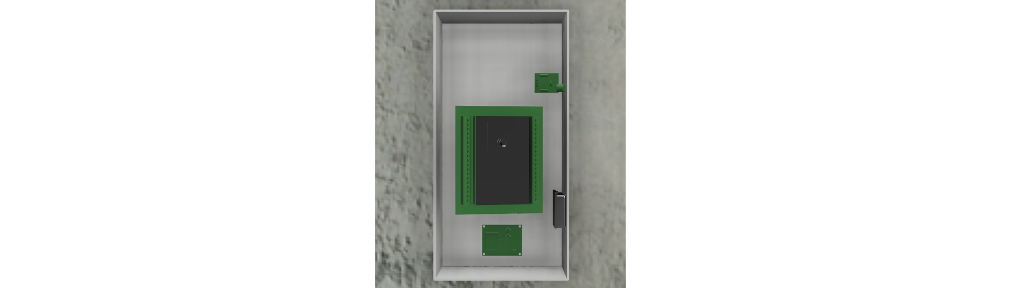
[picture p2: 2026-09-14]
model/SafeWay7.png

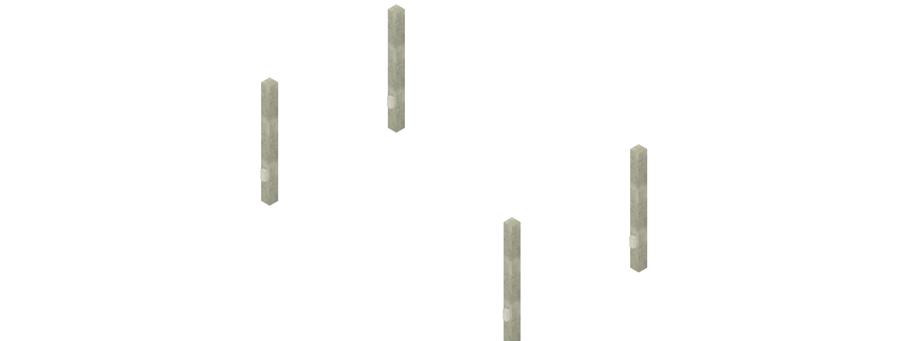
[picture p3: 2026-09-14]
model/SafeWay1.png

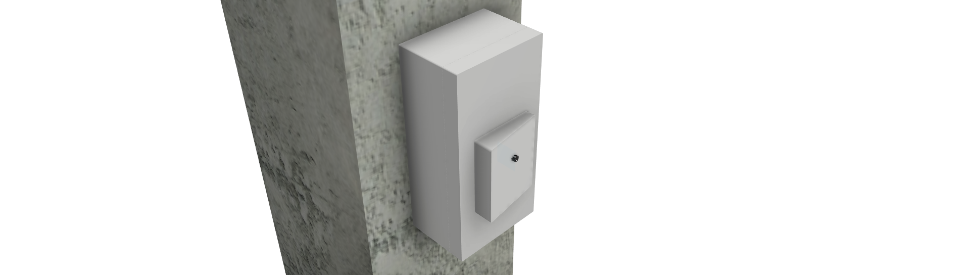
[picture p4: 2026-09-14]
model/SafeWay4.png

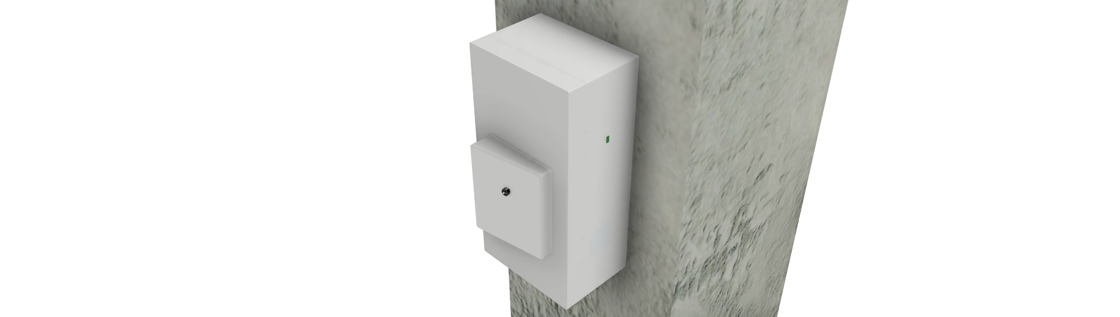
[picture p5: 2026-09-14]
model/SafeWay3.png

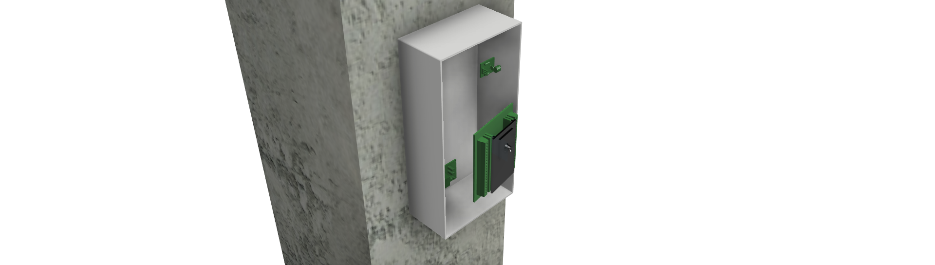
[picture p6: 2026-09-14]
model/SafeWay5.png

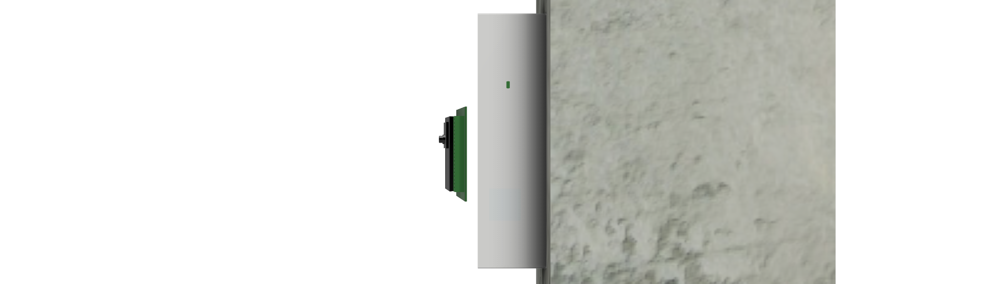
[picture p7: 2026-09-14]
model/SafeWay8.png

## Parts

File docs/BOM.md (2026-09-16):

# SafeWay — Bill of Materials (BOM)

**Project:** IoT Vehicle Speed Monitoring System (CDM324 24 GHz Doppler radar + laser break-beam confirm + two-board ESP32 architecture)
**Source:** Lazada Philippines · Prices checked **Sep 7–10, 2026**
**Criteria:** 3+ rating where available, proven sales (sold count), local PH sellers preferred, cheapest that qualifies.
**Note:** Lazada prices move with vouchers/promos — treat totals as estimates (±10%).

---

## Architecture (drives this BOM)

```mermaid
flowchart LR
    subgraph HUB["ESP32 38-pin HUB — sensor board"]
        H1["CDM324 radar OUT → GPIO 34<br/>Doppler pulse counting"]
        H2["Laser receiver #1 DO → GPIO 25<br/>presence confirm"]
        H3["Buzzer → GPIO 27<br/>overspeed alert"]
    end
    subgraph CAM["ESP32-S3 WROOM N16R8 CAM — camera board"]
        C1["Laser receiver #2 DO → GPIO 21<br/>self-trigger"]
        C2["OV5640 plate snapshot<br/>at beam #2 break + microSD save"]
        C3["/stream polled live frame<br/>native USB-C flashing — no programmer board"]
    end
    subgraph FAR["FAR POST — opposite side of the lane"]
        F1["KY-008 laser TX #1, always-on — own supply #1"]
        F2["KY-008 laser TX #2, always-on — own supply #2"]
        F3["red dots cross the lane to the two receivers<br/>no cable to the hub pole — self-powered"]
    end
    HUB <-. "same WiFi network — zero wires between boards" .-> CAM
    F1 -. "beam #1" .-> H2
    F2 -. "beam #2" .-> C1
```

**Why two boards:** the classic AI-Thinker ESP32-CAM starves you for pins (camera + SD leaves ~2–3 usable GPIOs — no room for radar, beam receiver, and buzzer). Splitting duties gives the sensors a full 38-pin board and the camera a dedicated board — each simpler to code, flash, and debug. (The ESP32-S3 camera board now has GPIOs to spare — one of them takes beam #2's receiver — but the split is kept anyway: radar pulse-counting never competes with camera DMA, and a camera reboot can't drop speed measurements.) They meet over WiFi; no wires between them, and **no cable crosses the road** — each far-post laser TX is self-powered.

**Full wiring diagram:** [wiring/circuit_image.png](../wiring/circuit_image.png) · editable [Cirkit Designer project](https://app.cirkitdesigner.com/project/192cfce5-5705-47b2-8c56-7a07da66e9da)

---

## Summary Table

| # | Component | Qty | Unit Price | Subtotal | Rating | Sold |
|---|---|-----|---:|---:|---|---|
| 1 | CDM324 24 GHz Doppler radar module (E-WOITD) | 1 | ₱184 | ₱184 | LazMall, 93% seller | — |
| 2 | ESP32-S3 WROOM N16R8 CAM board + OV5640 5MP camera | 1 | ₱613 | ₱613 | 5.0 (3) · 91% store | — |
| 3 | ESP32 38-pin dev board, CP2102, Type-C (DIYUSER) | 1 | ₱196 | ₱196 | 4.8★ (81) | 822 |
| 4 | KY-008 laser transmitter + laser receiver module pair (Layad Circuits) | **2 pairs** | ₱253 | ₱506 | 97% seller · 4.7K sold store | — |
| 5 | LM358 dual op-amp DIP-8 (2 pcs, radar signal conditioner) | 1 pack | ₱25 | ₱25 | — | 370 |
| 6 | Active buzzer 5V | 1 | ₱30 | ₱30 | 5.0 (42) | 174 |
| 7 | Kingston microSD 16GB Class 10 | 1 | ₱219 | ₱219 | 4.8 (265) | 1.0K |
| 8 | Dupont jumper wires 40-pin (M-F / M-M) | 2 sets | ₱39 | ₱78 | 4.8 (2,814) | 23.2K |
| 9 | Breadboard 830 points (SYB MB-102) | 1 | ₱29 | ₱29 | 4.8 (1,959) | 15.0K |
| 10 | 5V 2A power supply adapter (DC 5.5×2.5mm jack) | 2 | ₱53 | ₱106 | 4.9 (324) | 4.5K |
| 11 | Weatherproof enclosure IP68 ABS (ALLAN 200×100×70) | 1 | ₱220 | ₱220 | 4.9 (1,545) | 14.5K |
| 12 | Compact 5V USB charger (far-post laser TX supply) | 2 | ₱55 | ₱110 | — | — |
| 13 | Zip ties 100pcs (mounting) | 1 | ₱12 | ₱12 | — | 153.8K |

**GRAND TOTAL (recommended build): ≈ ₱2,328**

---

## Why the CDM324?

The **CDM324** (InnoSent IPM165 die) is a 24.125 GHz homodyne Doppler radar. Movement in its beam mixes down to an audio-frequency **IF signal whose frequency is directly proportional to speed**:

```
f_doppler (Hz) = 44.7 × speed (km/h)
```

The E-WOITD module sold on Lazada PH is the ICStation-style board with onboard two-stage amplification — the same module family used in public Arduino speed-meter projects (kd8bxp's 24 GHz Doppler speed sketch, JChav02's P10 speed sign). The 38-pin ESP32 just counts pulses on one GPIO; no ADC, no FFT, no radar-gun expertise needed.

**Range:** roughly 10–30 m on a car-sized target (module gain dependent). More than enough for a campus lane.

> **Note on the paper:** the reference study (safeway.pdf) specced **two IR break-beam sensors** for speed and an HC-SR04 as "supplementary detection (optional redundancy)". This build replaces all of them: the **CDM324 radar** takes over speed measurement (direct, physics-exact, no sun-blind receivers, no beam alignment, better multi-lane behavior), and a **KY-008 laser break-beam pair** takes over presence confirmation — same break-beam principle as the paper's IR gates but at visible 650 nm with a photodetector-based receiver module, so it isn't fooled by sunlight the way raw IR photodiodes are, and it spans the lane on a cheap 2-wire run. The HC-SR04 is dropped entirely (no ultrasonic in this build).

---

## Detailed Listings

### 1. CDM324 24GHz Doppler Radar Sensor Module
- **Price:** ₱177.96–₱184.23 (promo fluctuates) · **Seller rating:** 93% · **Sold:** 22.7K store-wide
- **Seller:** E-WOITD (LazMall) · **Location:** China dropship
- **URL:** https://www.lazada.com.ph/products/pdp-i15517814385.html
- **Backup:** SD&HI same-module listing — https://www.lazada.com.ph/products/pdp-i15590847730.html (₱195.90)
- **Backup 2 (HB100 10.525 GHz alternative, local):** Meterk HB100 Doppler module, ₱207, Bulacan — https://www.lazada.com.ph/products/pdp-i1555917163.html — *different Doppler constant (31.36 Hz per mph); firmware change required if used*
- Note: "Radar Induction Switch" in the name is standard marketing title for this module family — the OUT pin carries the **amplified Doppler IF**, proven speed-readable by multiple public Arduino projects. Verify yours per [HARDWARE.md §IF verification](HARDWARE.md#3-if-signal-verification-do-this-first) before mounting.

### 2. ESP32-S3 WROOM N16R8 CAM Development Board + OV5640 (camera board)
- **Price:** ₱612.85 — select the **"Esp32-s3 development board + domestic ov5640"** variant (board-only variant ₱364.65; board + OV2640 variant cheaper) · promo moves daily
- **Rating:** 5.0 (3) · **Seller:** 91% · 15.1M sold store-wide · 8-year store · 96% ships in 48 h
- **URL:** https://www.lazada.com.ph/products/pdp-i5315228212.html — *pick the "+ domestic ov5640" variant at checkout*
- **Specs:** ESP32-S3-WROOM-1 **N16R8** (16 MB flash, 8 MB octal PSRAM), **OV5640** camera on a 24-pin FPC header, **onboard microSD/TF slot**, dual USB Type-C (native USB-OTG + USB-to-UART), WiFi 4 + BT 5. GPIOs are **3.3 V only** (not 5 V tolerant).
- **Why this over the ESP32-CAM-MB:** no programmer board at all — native USB-C flashing replaces the MB/CH340 + IO0-jumper dance; 8 MB PSRAM buffers the OV5640's larger frames (the old AI-Thinker CAM chokes above VGA); the 24-pin FPC header accepts both OV2640 and OV5640; and the onboard microSD keeps the violation-photo local backup.
- **Compatibility (validated Sep 10, 2026):** ESP32-S3 is a supported SoC and OV5640 a supported sensor (up to 2592×1944) in the official espressif [esp32-camera](https://github.com/espressif/esp32-camera) driver; this exact board family (DIYables / Goouuu / Edgehax rebrands of the same design) is sold worldwide with the OV5640 variant, onboard microSD, and Arduino support via board = **ESP32S3 Dev Module**, PSRAM = **OPI PSRAM**.
- **Budget variant (same page):** board + OV2640 — same board, 2MP camera; still readable for plates at close lane distances, saves ~₱100.
- **Firmware note:** FIRMWARE.md's `safeway-cam` sketch now ships with this board's verified pin map (DVP bus Y2–Y9 = GPIO 11/9/8/10/12/18/17/16, XCLK 15, PCLK 13, VSYNC 6, HREF 7, SIOD 4, SIOC 5; SD_MMC CLK 39 / CMD 38 / D0 40) — cross-checked against two independent sources. Confirm against the printed pinout card on first boot anyway.

### 3. ESP32 38-Pin Development Board (sensor hub)
- **Price:** ₱196.39 · **Rating:** 4.8★ (81) · **Sold:** 822
- **Seller:** DIYUSER · **Location:** overseas dropship
- **URL:** https://www.lazada.com.ph/products/pdp-i4409112955.html
- **Specs:** ESP-WROOM-32, CP2102 USB-serial, Type-C, dual-core, WiFi/BT — the standard DOIT ESP32 DevKit v1 38-pin layout every tutorial uses.
- **Why 38-pin over 30-pin:** camera-free board = all its pins available; 38-pin is the full DevKit layout (more GPIOs + both I2C/SPI banks broken out) with the most tutorial coverage for sensor work.
- **Backup:** CP2102 WROOM 38Pin Type-C ₱178.80, 293 sold — https://www.lazada.com.ph/products/ (search "CP2102 WROOM ESP32 38Pin Type-C" — NEW listing at 75% off)
- **Backup 2 (local, Bulacan):** PowerMav ESP32 38-pin Type-C ₱233 — search "ESP32 38 Pin Module Type C" on Lazada
- **Why the hub stays on a WROOM-32 (not S3):** the S3's extras (camera DVP bus, PSRAM, vector/AI instructions) all live on the camera board now; the sensor hub needs none of them — the WROOM-32 is ₱196, runs the same Arduino core, and has more free pins than the hub uses.

### 4. KY-008 Laser Transmitter + Laser Receiver Module Pair (presence confirmation)
- **Price:** ₱253.00 (pair — select the "Transmitter&Receiver" variant) · **Seller:** Layad Circuits (Benguet) · **Seller rating:** 97% · 4.7K sold by store · 5-year store, 100% ships in 48 h
- **URL:** https://www.lazada.com.ph/products/pdp-i5141273577.html
- **Backup (TX only):** KY-008 module from Fulabs ₱44 — https://www.lazada.com.ph/products/pdp-i5367051449.html (pair it with a separate laser-receiver module; e.g. "Laser Receiver Sensor" ₱165, Laguna — https://www.lazada.com.ph/products/pdp-i4352848577.html)
- **Backup 2 (kit):** "KY-008 Laser Transmitter + Non-Modulator Laser Receiver Module Kit" ₱626 — https://www.lazada.com.ph/products/pdp-i15568605059.html
- Role: **beam #1** — KY-008 TX #1 sits on the far post (650 nm red laser, ~5 mW, always-on), receiver #1 sits on the hub pole → hub GPIO 25: confirms the radar event. **beam #2** — KY-008 TX #2 (far post) + receiver #2 on the CAM board → **GPIO 21**: the CAM self-triggers its plate snapshot the instant the beam breaks and caches the frame for the hub's `/capture` fetch. This replaces the paper's IR break-beam concept with a visible-light version that resists sunlight interference.
- KY-008 pinout: **S = signal** (tie to 5 V for always-on — simplest), **middle = +5 V**, **− = GND**. Draws < 30 mA.
- **Safety note:** 5 mW / 650 nm is Class 3R-adjacent — never look into the beam, don't aim at eye level of drivers/pedestrians; mount it low (plate height) and aim it across the lane at the receiver, not along it.

### 5. LM358 Dual Op-Amp DIP-8 (2 pcs) — radar signal conditioner
- **Price:** ₱25.00 (2 pieces) · **Sold:** 370 · **Location:** Bulacan
- **URL:** https://www.lazada.com.ph/products/pdp-i3251664504.html *(same seller family as prior verified listing — if rotated: search "LM358 DIP" pick Bulacan seller)*
- Alternative prebuilt: "LM358 100× Gain Signal Amplification Module" ₱148, Bulacan — zero soldering if your module's IF output turns out weak.
- Note: Wired into this build's radar chain (CDM324 → LM358 → GPIO 34) so weak-IF module batches still trigger the hub cleanly — full schematic in [HARDWARE.md §4](HARDWARE.md#4-lm358-signal-conditioner-radar-chain). If your module's OUT already swings healthy pulses (§3 bench check), it can also run direct.

### 6. Active Buzzer 5V (alarm/alert)
- **Price:** ₱30.00 · **Rating:** 5.0 (42) · **Sold:** 174 · **Location:** Metro Manila
- **URL:** https://www.lazada.com.ph/products/pdp-i4216290365.html
- Note: **Active** buzzer (built-in oscillator). "1-PC per ORDER". Select 5V.
- **Backup:** ₱23, 73 sold, (8), Benguet — https://www.lazada.com.ph/products/pdp-i4908420831.html

### 7. Kingston microSD Card 16GB Class 10 (U1)
- **Price:** ₱219 (select **16GB** variant — page defaults to 512GB at ₱549) · **Rating:** 4.8 (265) · **Sold:** 1.0K
- **Seller:** vgsvny store · **Location:** Quezon City
- **URL:** https://www.lazada.com.ph/products/pdp-i1806785852.html
- Note: Slides into the **camera board's onboard microSD slot** — local backup of every violation photo ([FIRMWARE.md](FIRMWARE.md) camera sketch saves alongside WiFi upload). Class 10 / U1 minimum.
- **Backup:** https://www.lazada.com.ph/products/pdp-i15448124514.html

### 8. Dupont Jumper Wires 40-pin (Male-Female + Male-Male)
- **Price:** ₱39.00 per set (2 sets budgeted: M-F module→breadboard, M-M rail jumps)
- **Sold:** 23.2K · **Rating:** 4.8 (2,814) · **Location:** Bulacan
- **URL:** https://www.lazada.com.ph/products/pdp-i5992263.html

### 9. Breadboard 830 Tie Points (SYB MB-102, full-size)
- **Price:** ₱29.00 · **Sold:** 15.0K · **Rating:** 4.8 (1,959) · **Location:** Bulacan
- **URL:** https://www.lazada.com.ph/products/pdp-i8845741.html

### 10. 5V 2A Power Supply Adapter (DC 5.5×2.5mm jack)
- **Price:** ₱53.00 each, **2 pcs budgeted** · **Sold:** 4.5K · **Rating:** 4.9 (324) · **Location:** Bulacan
- **URL:** https://www.lazada.com.ph/products/pdp-i3062233761.html
- Note: the system runs on **four independent supplies** — #3 powers the 38-pin hub (radar + receiver #1 + buzzer), #4 powers the camera board (feed its **5V/VIN pin** from the adapter leads, or plug any USB-C charger into its Type-C port), and each far-post laser TX (#1, #2) runs on its own compact supply at the far post (any 5V ≥1A source — the TX draws < 30 mA). No cable crosses the road; a supply failure can never cascade between beams or boards (a CAM reboot can't brown-out the radar, a dead far-post supply can't dim the other beam).
- **Backup:** ₱55, 5.5K sold — https://www.lazada.com.ph/products/pdp-i2442570467.html

### 11. Weatherproof Enclosure — ALLAN IP68 ABS Junction Box
- **Price:** ₱220 (200×100×70mm variant) · **Rating:** 4.9 (1,545) · **Sold:** 14.5K
- **Seller:** ALLAN.PH (LazMall) · **Location:** Quezon City
- **URL:** https://www.lazada.com.ph/products/pdp-i2890018648.html
- Note: 200×100×70 fits the 830-point breadboard + 38-pin board + camera board + radar wiring. **24 GHz passes through ABS plastic** — radar can sit behind a plain plastic wall (no metal!). The camera needs a window — see [HARDWARE.md §7](HARDWARE.md#7-enclosure-assembly-ip68-abs-200x100x70-mm).
- **Budget alt:** IP65 ABS box ₱27.50 — https://www.lazada.com.ph/products/pdp-i5215693124.html (light rain only)

### 12. Compact 5V USB Charger (far-post laser TX supply) — 2 pcs
- **Price:** ≈ ₱55 each (any compact 5V ≥1A USB charger + short USB cable works — Lazada generic, e.g. https://www.lazada.com.ph/products/pdp-i3100389517.html or search "5V 1A USB charger")
- Role: supplies #1 and #2 — each KY-008 TX on the far post runs on its own charger inside its housing (TX draws < 30 mA). With the battery backup ([§5.5](HARDWARE.md#55-battery-backup-ups-option--one-18650-per-supply)) the charger now feeds the UPS branch: charger → SS34 → TX rail, charger → TP4056 → 18650 → MT3608 → TX rail.

### 13. Cable/Zip Ties 100pcs (mounting + cable management)
- **Price:** ₱12.00 · **Sold:** 40K+ · **Location:** Bulacan
- **URL:** https://www.lazada.com.ph/products/pdp-i7109771.html *(or search "zip ties 100pcs")*

---

## Battery Backup Add-On (UPS + 18650) — 4 devices/poles

Bolt-on UPS branch per supply so a mains outage never stops a measurement, snapshot, or beam (design + sizing table: [HARDWARE.md §5.5](HARDWARE.md#55-battery-backup-ups-option--one-18650-per-supply)). Lazada prices checked Sep 2026 — verify before ordering.

| # | Component | Qty (per device) | Qty (4 devices) | Unit | Subtotal | Rating / Sold | URL |
|---|---|---:|---:|---:|---:|---|---|
| B1 | LiitoKala Lii-35S+ 18650 3500 mAh protected cell | 4 | **16** | ≈ ₱125 | ₱2,000 | LiitoKala store, 4.8★ · 554 sold (2-pc listing) | https://www.lazada.com.ph/products/pdp-i15527417666.html |
| B2 | 18650 single holder w/ wire leads | 4 | 16 | ≈ ₱20 | ₱320 | 4.9★ · 3.7K sold | https://www.lazada.com.ph/tag/18650-battery-holder-with-wire/ (search single) |
| B3 | TP4056 Type-C/MicroUSB 1 A charger + protection | 4 | 16 | ₱25 | ₱400 | 4.9★ · 10.6K sold, Bulacan | https://www.lazada.com.ph/products/type-c-micro-usb-5v-1a-18650-tp4056-lithium-battery-charger-module-charging-board-with-protection-i109875975.html |
| B4 | MT3608 boost module (set 5.0 V) | 4 | 16 | ₱26 | ₱416 | 4.7★ · 267+ (tag ≥ 4.7★) | https://www.lazada.com.ph/products/pdp-i3406468475.html |
| B5 | SS34 3 A 40 V Schottky (backfeed blocking) | 4 | 16 | ≈ ₱3 | ₱48 | 5.0★ · 52 (tag) | https://www.lazada.com.ph/products/pdp-i15606165072.html |
| | **Battery backup total** | | | | **≈ ₱3,184** | ≈ ₱796/device | |

**Config per device:** every supply (#1–#4) — hub, CAM, and **both far-post laser TXs** — gets exactly **one protected 18650 in a single holder** + TP4056 + MT3608 @ 5.0 V + SS34 — no fuse, no paralleling, no balancing needed (4 h max runtime sizing: [HARDWARE.md §5.5](HARDWARE.md#55-battery-backup-ups-option--one-18650-per-supply)). The beams are battery-backed too: a mains outage can't kill either laser.

**Costs:** ≈ ₱796/device on top of the ₱2,328 recommended build → **≈ ₱3,124/device, ≈ ₱12,496 for all four poles** — laser beams included. Recommended with it: the two far-post IP65 boxes (Deluxe option, +₱120) since the TX housings now hold the UPS branch.

**Critical:** use only **protected** cells (TP4056-with-protection) and one cell per holder — never parallel cells in this design; charge each cell fully before install.

---

## Budget variants

| Build | What changes | Total |
|---|---|---:|
| **Recommended** (as above) | — | **≈ ₱2,328** |
| **Bare-bones bench POC** | IP65 box (−₱192); one 2A adapter per board side + rail caps, USB power banks for the TXs instead of chargers (−₱110); skip zip ties (−₱12); one jumper set (−₱39) | ≈ ₱1,975 |
| **Deluxe** | Prebuilt LM358 amp module instead of ICs (+₱123); small IP65 boxes (e.g. ₱60 each) on the far post for the laser TXs (+₱120) | ≈ ₱2,571 |
| **Single beam (hub-only)** | Drop beam #2 (−₱253): CAM serves on-demand `/capture` as before — the hub's beam-break fetch becomes a close-time fetch; confirm logic (beam #1) unaffected | ≈ ₱2,075 |
| **No far post available?** | Skip both cross-lane beams (−₱506 −₱110) and run radar-only with `MIN_SPEED_KPH` raised — records stay but lose the two-sensor confirm flag | ≈ ₱1,712 |

Parts verified Sep 6–8, 2026; camera board swapped ESP32-CAM-MB → ESP32-S3 + OV5640 and re-verified Sep 10, 2026. Re-check prices before ordering — Lazada promo pricing moves daily.

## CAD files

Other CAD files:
model/SafeWay.f3z

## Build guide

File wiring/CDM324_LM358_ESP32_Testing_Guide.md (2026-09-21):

# CDM324 + LM358 Signal Conditioner
## Step-by-Step Build and Testing Guide

> ⚠️ **IMPORTANT**
>
> Huwag buuin at ikonekta ang buong circuit nang sabay-sabay.
> Ang bawat section ay kailangang **i-build, i-measure, at i-confirm**
> gamit ang multimeter bago pumunta sa susunod na section.
>
> **Huwag ikonekta ang LM358 output sa ESP32 GPIO34 hangga't hindi
> pa nakukumpirma ang output voltage.**

---

## 1. Goal ng Circuit

Ang basic signal path ay:

```text
CDM324 Radar
     │
     ▼
Weak analog signal
     │
     ▼
LM358 Amplifier
     │
     ▼
Signal Conditioning
     │
     ▼
ESP32 GPIO34
```

Ang CDM324 signal ay maaaring mahina, kaya ginagamit ang LM358
upang palakasin ito.

Pero ang amplifier output ay **hindi automatic na safe para sa ESP32**.
Kailangan muna itong sukatin at i-condition.

---

# 2. Build Order

Sundin ang sequence na ito:

```mermaid
flowchart TD
    A["Power"] --> B["2.5V Bias"]
    B --> C["Test Bias Voltage"]
    C --> D["LM358 Stage 1"]
    D --> E["Test Stage 1"]
    E --> F["LM358 Stage 2"]
    F --> G["Test Stage 2"]
    G --> H["CDM324 Signal Test"]
    H --> I["Connect Radar to Amplifier"]
    I --> J["Measure Amplified Signal"]
    J --> K["3.3V Protection / Comparator"]
    K --> L["Test Digital Output"]
    L --> M["ESP32 GPIO34"]
```

### Important Rule

> **Kung bumagsak ang isang test, huwag muna pumunta sa susunod na step.**
> Ayusin muna ang kasalukuyang stage.

---

# 3. LM358 Pinout

Gamitin ang DIP-8 LM358 na may notch sa taas:

```text
             LM358
        ┌─────────────┐
 OUT A  │ 1         8 │ VCC
 IN− A  │ 2         7 │ OUT B
 IN+ A  │ 3         6 │ IN− B
 GND    │ 4         5 │ IN+ B
        └─────────────┘
             notch
```

| Pin | Function |
|---|---|
| 1 | Output A |
| 2 | Inverting Input A (-) |
| 3 | Non-inverting Input A (+) |
| 4 | GND |
| 5 | Non-inverting Input B (+) |
| 6 | Inverting Input B (-) |
| 7 | Output B |
| 8 | VCC |

---

# 4. Stage 1 — Power Test

## 4.1 LM358 Power Connections

Ikonekta muna ang **power lamang**.

- LM358 Pin 8 → +5V
- LM358 Pin 4 → GND
- 100nF ceramic capacitor → between Pin 8 and Pin 4

```mermaid
flowchart LR
    VCC["+5V"] --> P8["LM358 Pin 8"]
    P4["LM358 Pin 4"] --> GND["GND"]

    P8 --- C["100nF"]
    C --- P4
```

---

## 4.2 Multimeter Test

I-set ang multimeter sa **DC Voltage**.

### Test A — VCC

```text
Red probe   → LM358 Pin 8
Black probe → GND
```

Expected:

```text
≈ 5.0 V
```

### Test B — GND

```text
Red probe   → LM358 Pin 4
Black probe → GND
```

Expected:

```text
≈ 0 V
```

### STOP CONDITION

Huwag magpatuloy kung:

- walang 5V sa Pin 8
- mali ang supply voltage
- hindi connected ang GND
- may abnormal na heating ang LM358

---

# 5. Stage 2 — Gumawa ng 2.5V Bias

Dahil single-supply ang LM358, gagawa tayo ng midpoint reference.

```mermaid
flowchart TD
    VCC["+5V"] --> R1["10kΩ"]
    R1 --> BIAS["2.5V Bias Point"]
    BIAS --> R2["10kΩ"]
    R2 --> GND["GND"]
```

Ang concept ay:

```text
       +5V
        │
       10kΩ
        │
        ├──── 2.5V Bias
        │
       10kΩ
        │
       GND
```

---

## 5.1 Test the 2.5V Bias

### Multimeter

```text
Red probe   → 2.5V Bias Point
Black probe → GND
```

Expected:

```text
≈ 2.5 V
```

Practical readings such as:

```text
2.4 V
2.5 V
2.6 V
```

may be acceptable depending on resistor tolerance and supply voltage.

> ⚠️ **DO NOT continue to the amplifier stage until the bias voltage
> has been measured.**

---

# 6. Stage 3 — LM358 Amplifier Stage 1

Sa unang test, **huwag muna ikonekta ang CDM324**.

Ang purpose muna natin ay makita kung tama ang bias at feedback
ng unang LM358 amplifier.

## 6.1 Connections

Gamitin:

- 100kΩ feedback resistor
- 10kΩ gain resistor

```mermaid
flowchart LR
    BIAS["2.5V Bias"] --> P3["LM358 Pin 3 (+)"]

    P1["Pin 1 OUT"] --> RF["100kΩ"]
    RF --> P2["Pin 2 (-)"]

    P2 --> RG["10kΩ"]
    RG --> BIAS
```

---

## 6.2 Calculate the Gain

Para sa non-inverting amplifier:

\[
A_v = 1 + \frac{R_f}{R_g}
\]

Kung:

\[
R_f = 100kΩ
\]

at:

\[
R_g = 10kΩ
\]

then:

\[
A_v = 1 + \frac{100kΩ}{10kΩ}
\]

\[
A_v = 11
\]

Kaya ang theoretical gain ng Stage 1 ay:

**×11**

---

## 6.3 Stage 1 DC Test

Dahil wala pa tayong radar signal, ang unang bagay na tinitingnan
natin ay ang **DC bias**.

Measure:

```text
Red probe   → LM358 Pin 1
Black probe → GND
```

Expected:

```text
Approximately 2.5 V
```

Hindi kailangang eksaktong 2.500V.

Halimbawa:

```text
2.3 V
2.4 V
2.5 V
2.6 V
```

ay maaaring acceptable depende sa actual circuit.

> ⚠️ Ang test na ito ay **bias test lamang**.
> Hindi pa nito pinapatunayang amplified na ang CDM324 signal.

---

# 7. Stage 4 — LM358 Amplifier Stage 2

Pumunta lamang dito kapag successful ang Stage 1 test.

Gamitin ang second amplifier ng LM358:

```text
Pin 5 = +
Pin 6 = -
Pin 7 = OUT
```

## 7.1 Connections

```mermaid
flowchart LR
    BIAS["2.5V Bias"] --> P5["LM358 Pin 5 (+)"]

    P7["Pin 7 OUT"] --> RF["100kΩ"]
    RF --> P6["Pin 6 (-)"]

    P6 --> RG["10kΩ"]
    RG --> BIAS
```

Ang theoretical gain ng Stage 2 ay:

\[
A_v = 1 + \frac{100kΩ}{10kΩ}
\]

\[
A_v = 11
\]

Kung parehong ginagamit ang dalawang stages:

\[
11 \times 11 = 121
\]

So ang theoretical total gain ay:

**×121**

> ⚠️ Huwag agad gumamit ng ×10,000 gain.
> Ang sobrang taas na gain ay maaaring magdulot ng clipping,
> saturation, at malaking amplification ng noise.

---

## 7.2 Stage 2 DC Test

Measure:

```text
Red probe   → LM358 Pin 7
Black probe → GND
```

Expected:

```text
Approximately 2.5 V
```

Kung ang output ay malapit sa:

```text
0 V
```

o:

```text
5 V
```

sa halip na nasa paligid ng midpoint, **stop muna** at i-check
ang wiring.

---

# 8. Stage 5 — CDM324 Signal Test

> ⚠️ **HUWAG agad ikonekta ang CDM324 sa LM358.**

Una, kailangang malaman ang actual signal ng **specific CDM324 module**
na ginagamit.

Ang pangalan ng output ay maaaring depende sa module/board implementation.
Huwag ipagpalagay na lahat ng CDM324 boards ay pareho.

---

## 8.1 Identify the Signal Output

Hanapin ang documented:

```text
OUT
IF
SIGNAL
```

o ang equivalent signal-output pin ng iyong module.

Kung hindi sigurado, tingnan muna ang schematic/datasheet ng
specific module.

---

## 8.2 Measure the Radar Output

Power the CDM324 according to its documented supply requirements.

Pagkatapos, sukatin muna ang suspected signal output relative sa GND.

```mermaid
flowchart LR
    RADAR["CDM324 Radar"] --> OUT["Signal OUT / IF"]
    OUT --> M["Multimeter / Oscilloscope"]
    GND["CDM324 GND"] --> M
```

I-record ang measurements:

```text
DC voltage:
________ V

Voltage with no moving target:
________ V

Voltage with moving target:
________ V

Approximate minimum:
________ V

Approximate maximum:
________ V
```

Kung may oscilloscope, mas useful dahil makikita ang actual waveform.

---

# 9. Stage 6 — Connect CDM324 to the Amplifier

Only proceed after the CDM324 output has been identified and measured.

Gamitin ang coupling capacitor kung required ng signal-conditioning
design.

General signal path:

```mermaid
flowchart LR
    RADAR["CDM324 OUT / IF"]
    C1["Coupling Capacitor"]
    A1["LM358 Stage 1"]
    C2["Coupling Capacitor"]
    A2["LM358 Stage 2"]

    RADAR --> C1
    C1 --> A1
    A1 --> C2
    C2 --> A2
```

> ⚠️ Ang exact capacitor polarity at value ay kailangang i-confirm
> batay sa measured DC level ng actual CDM324 output at sa final
> amplifier topology.

---

# 10. Stage 7 — Measure the Amplified Signal

Pagkatapos ikonekta ang radar signal, **huwag muna ikonekta sa ESP32**.

Measure the LM358 output first.

```mermaid
flowchart LR
    RADAR["CDM324"] --> AMP["LM358 Amplifier"]
    AMP --> OUT["LM358 Output"]
    OUT --> M["Multimeter / Oscilloscope"]
    GND["GND"] --> M
```

Measure:

```text
Minimum voltage:
________ V

Maximum voltage:
________ V

Idle voltage:
________ V
```

Kung may oscilloscope:

```text
Idle waveform:
____________________

Motion waveform:
____________________
```

---

# 11. IMPORTANT — ESP32 GPIO34 Test Gate

> 🚨 **DO NOT CONNECT LM358 OUTPUT DIRECTLY TO GPIO34 YET.**

Ang ESP32 ay gumagamit ng **3.3V logic**.

Ang LM358 naman ay maaaring ma-supply ng 5V at ang output nito
ay maaaring lumampas sa safe range na gusto nating gamitin para
sa ESP32.

Kaya kailangan munang sukatin ang maximum output.

---

## 11.1 Measure LM358 Output

```mermaid
flowchart LR
    LM["LM358 OUT"] --> M["Multimeter / Oscilloscope"]
    GND["Circuit GND"] --> M
```

Record:

```text
Idle:
______ V

Minimum:
______ V

Maximum:
______ V
```

**Huwag mag-assume na safe dahil lamang mukhang maliit ang signal.**

---

# 12. Recommended Digital Signal Stage

Kung ang goal ay makakuha ng clean HIGH/LOW pulses,
mas magandang magkaroon ng comparator o Schmitt-trigger stage.

Recommended architecture:

```mermaid
flowchart LR
    CDM["CDM324 Radar"]
    A1["LM358 Stage 1"]
    A2["LM358 Stage 2"]
    COMP["Comparator / Schmitt Trigger"]
    ESP["ESP32 GPIO34"]

    CDM --> A1
    A1 --> A2
    A2 --> COMP
    COMP --> ESP
```

Ang purpose ng comparator:

```text
Analog waveform
      │
      ▼
Comparator
      │
      ├──── LOW
      │
      └──── HIGH
```

Sa ganitong paraan, hindi kailangang hulaan ng ESP32 kung anong
analog voltage ang ibig sabihin ng "motion".

---

# 13. Final ESP32 Connection

Kapag na-test na ang signal-conditioning stage at napatunayang
ESP32-compatible ang output:

```mermaid
flowchart LR
    COMP["Comparator Output"] --> GPIO["ESP32 GPIO34"]
    GND1["Circuit GND"] --- GND2["ESP32 GND"]
```

Important:

- GPIO34 is input-only.
- Ang signal ay dapat compatible sa 3.3V logic.
- Dapat common ang signal ground ng ESP32 at signal-conditioning circuit
  kung required ng final design.

---

# 14. Complete Tested Signal Path

Kapag successful na ang bawat individual test:

```mermaid
flowchart LR
    CDM["CDM324 Radar"]
    C1["Input Coupling"]
    A1["LM358 Stage 1"]
    C2["Interstage Coupling"]
    A2["LM358 Stage 2"]
    COMP["Comparator / Schmitt"]
    GPIO["ESP32 GPIO34"]

    CDM --> C1
    C1 --> A1
    A1 --> C2
    C2 --> A2
    A2 --> COMP
    COMP --> GPIO
```

---

# 15. Testing Checklist

Gamitin ang checklist na ito habang nag-aassemble:

```text
[ ] LM358 Pin 8 = approximately +5V
[ ] LM358 Pin 4 = 0V
[ ] 100nF decoupling capacitor installed
[ ] 2.5V bias created
[ ] 2.5V bias measured
[ ] Stage 1 wired
[ ] Stage 1 DC output tested
[ ] Stage 2 wired
[ ] Stage 2 DC output tested
[ ] CDM324 signal pin identified
[ ] CDM324 signal measured before connection
[ ] Radar connected to amplifier
[ ] Amplifier output measured
[ ] Maximum amplifier output measured
[ ] Comparator / protection stage tested
[ ] Comparator output confirmed as 3.3V-compatible
[ ] Only then connect to GPIO34
```

---

# 16. Troubleshooting Flow

```mermaid
flowchart TD
    START["Test Current Stage"] --> V{"Expected Voltage?"}

    V -- "YES" --> NEXT["Proceed to Next Stage"]
    V -- "NO" --> CHECK["Check Wiring / Component Values"]

    CHECK --> POWER["Check Power"]
    POWER --> GND["Check Ground"]
    GND --> RES["Check Resistor Values"]
    RES --> PIN["Check LM358 Pin Numbers"]
    PIN --> RETEST["Measure Again"]

    RETEST --> V
```

---

# 17. Why We Test Before Connecting Everything

Ang pangunahing rule ng tutorial na ito ay:

```text
BUILD
  ↓
MEASURE
  ↓
COMPARE WITH EXPECTED VALUE
  ↓
PASS?
 ├── NO → TROUBLESHOOT
 │
 └── YES
       ↓
    NEXT STAGE
```

Hindi ibig sabihin na kapag nakita mo ang complete schematic,
kailangan mong ikonekta agad lahat.

Ang complete schematic ay **reference ng buong system**.

Ang actual assembly ay ginagawa nang **paunti-unti at sinusukat
ang bawat stage**.

---

# 18. Important Notes

### About ×10,000 Gain

Ang original theoretical configuration na:

\[
101 \times 101 = 10,201
\]

ay maaaring maging sobrang taas para sa unang prototype.

Halimbawa:

\[
0.5mV \times 10,000 = 5V
\]

At kung mas mataas pa ang input signal, magki-clip ang amplifier.

Para sa initial testing, mas madaling magsimula sa:

\[
11 \times 11 = 121
\]

at dagdagan lamang ang gain pagkatapos masukat ang actual CDM324 signal.

### About the LM358

Ang LM358 ay analog operational amplifier.
Hindi ito automatic na digital pulse generator.

Kung kailangan ng ESP32 ng clean digital pulses:

```text
LM358
  ↓
Comparator / Schmitt Trigger
  ↓
ESP32 GPIO34
```

ay mas predictable kaysa direktang analog output papunta sa GPIO.

### About GPIO34

GPIO34 ay input-only.

Huwag itong gamitin bilang output.

At huwag ikonekta ang isang unknown-voltage signal dito nang hindi
muna sinusukat ang maximum voltage.

---

# 19. Final Rule

> **MEASURE FIRST. CONNECT SECOND.**

Huwag hulaan ang voltage.

Huwag ipagpalagay na pareho ang lahat ng CDM324 modules.

Huwag ipagpalagay na ang LM358 output ay safe para sa ESP32.

Ang tamang sequence ay:

```text
Power
  ↓
Measure
  ↓
Bias
  ↓
Measure
  ↓
Amplifier
  ↓
Measure
  ↓
Radar
  ↓
Measure
  ↓
Signal conditioning
  ↓
Measure
  ↓
ESP32
```

Ito ang approach na gagamitin natin para maging safe at madaling sundan
ang prototype.

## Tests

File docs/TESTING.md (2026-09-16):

# Testing & Calibration Guide

Bench validation, Doppler calibration, and the formal evaluation protocol from the capstone methodology (PPDIOO **Operate** phase, scored against ISO/IEC 25010 and 30141).

**Estimated time:** half-day bench + 1–2 days field

---

## 1. Bench Tests (before going outside)

Run in order — each gates the next. With two boards, several tests are per-board. Before B1, eyeball the build against the [full wiring diagram](../wiring/circuit_image.png).

| # | Test | Pass criteria |
|---|---|---|
| B1 | Power rails (both boards) | Each 5V rail 4.8–5.2 V under WiFi load; hub rail stays flat when CAM reboots |
| B2 | Radar IF verification | [HARDWARE.md §3](HARDWARE.md#3-if-signal-verification-do-this-first) — hand-wave gives 100–2,000 Hz waveform on serial; idle is flat |
| B3 | Hub boot | No boot loop; `SafeWay HUB ready` in serial monitor |
| B4 | CAM boot | `CAM ready at http://<ip>` printed; `/capture` returns a JPEG in a browser |
| B5 | Live frame | `/stream` returns a JPEG in a browser; the dashboard's live pane refreshes ~1/s |
| B6 | Break-beam #1 sanity | Block the beam with a book at ~1 m → hub prints `BEAM BROKEN`; remove → intact; boot line shows beam state |
| B6b | Break-beam #2 sanity (CAM) | Block beam #2 → CAM serial prints `BEAM2 SNAP → SD ok` and a new `/sw_*.jpg` appears on the microSD; remove → intact |
| B7 | Buzzer | Sounds while speed > limit during an event; silent otherwise |
| B8 | WiFi + API | `POST /api/incidents` returns 201 on a simulated violation |
| B9 | SD backup | Photo exists on the CAM's microSD after an event, even with the API down |
| B10 | Beam-break snapshot | With `SPEED_LIMIT_KPH` temporarily set to 5: open a radar event (wave over the radar), then block beam #2 → CAM caches the frame; the hub's fetch (block beam #1 too) returns the **cached beam-moment JPEG** — hub prints `SNAPSHOT: ok` **within ~1 s of the block** (not at event close); the logged incident carries the photo |
| B11 | Stale-cache fallback | Wait > `BEAM2_FRESH_MS` (8 s) after a beam-#2 break, then request `/capture` → CAM serves a **live grab**, not the stale plate frame |
| B12 | UPS transfer (per [HARDWARE.md §5.5](HARDWARE.md#55-battery-backup-ups-option--one-18650-per-supply), each supply) | Pull mains while under load: rail holds ≥ 4.9 V, hub serial keeps counting Hz, CAM stream doesn't drop; mains back → TP4056 charging LED lights |
| B13 | UPS runtime soak (each hub + CAM rail, once per device before acceptance) | Run the rail on battery only for 4 h under normal load: still ≥ 4.9 V at hour 4, hub logs events the whole time, cell recharges fully overnight afterwards |

## 2. Speed Calibration (the critical test)

The measurement chain is: **Doppler Hz ÷ 44.7 = km/h** (+ cosine correction). Calibrate against ground truth — a phone GPS speedometer app (±1–2 km/h, acceptable for POC) or a car at fixed RPM.

### Setup

- Radar mounted at its intended pole position/angle (bench rig works if it can see the test lane)
- Reference: phone GPS speedometer held by the passenger, **or** bicycle with a cycling computer, **or** car at fixed RPM (compute kph = RPM ÷ 60 × gear-adjusted wheel revs × circumference × 3.6 for a true ground truth)

### Reference speeds (no radar gun needed)

| Method | Expected speed |
|---|---|
| Walking briskly | 5–8 km/h |
| Jogging | 9–12 km/h |
| Bicycle (steady) | 15–25 km/h |
| Car at idle creep in 1st, no throttle | 8–12 km/h |
| Phone GPS speedometer (any vehicle) | live reference |

> Human/bike targets reflect the radar weakly (small radar cross-section) — a **car** gives the strongest, cleanest Doppler tone. Do the primary calibration with the car; use walk/bike passes only for coarse sanity.

### Procedure

1. Drive the car past the radar **10× at ~3 steady speeds** (e.g. ~15, ~30, ~45 km/h by GPS).
2. Record displayed peak vs GPS reference per pass in the log below.
3. Compute error: `error% = (displayed − reference) / reference × 100`.

### Pass thresholds (POC)

| Metric | Threshold |
|---|---|
| Mean absolute error | ≤ **10%** (paper's POC tolerance) |
| Consistency (σ of repeated same-speed runs) | ≤ 3 km/h |
| Detection rate (events captured / passes made) | ≥ **95%** |

### Interpreting systematic errors

| Pattern | Cause | Fix |
|---|---|---|
| Error constant multiplicative (~all reads −5%) | Cosine error — radar angled off-axis | Measure the mount angle; set `COSINE_ANGLE_DEG` |
| Reads ~½ expected | Radar module variant with different IF scaling (or LM358 amp clipping) | Re-run [HARDWARE.md §3](HARDWARE.md#3-if-signal-verification-do-this-first); if constant factor confirmed, recalibrate `HZ_PER_KPH` and document it |
| Random ±30% | Weak IF, noisy trigger | Check the LM358 conditioner build ([HARDWARE.md §4](HARDWARE.md#4-lm358-signal-conditioner-radar-chain)) — verify the 2.5 V bias node and re-run the §3 hand-wave test |

## 3. Response Time

- Radar detects overspeed → buzzer ON: ≤ ~400 ms worst case (a reading only exists at each 300 ms window close — the window is the resolution).
- Event close (lane clear + 1.5 s) → record visible in dashboard: stopwatch 5 runs; POC target **≤ 10 s** (the POST dominates — the photo is already buffered from the beam-break snapshot; sub-5 s on campus LAN).
- Beam-break → `SNAPSHOT: ok` on serial: ≤ ~1 s from the block (the CAM's self-triggered capture is near-instant; the hub's fetch of the cached frame follows within the same window).
- Log both in the template below.

## 4. Reliability / Soak Test

- Run both boards continuously for **48 h** (bench, aimed at a walkway with occasional traffic).
- Pass: no reboots, no missed events, no WiFi drops > 3 min, CAM microSD has all photos, hub serial shows no brownout resets.
- **Two-board specific:** power-cycle the CAM mid-soak (simulating a camera crash). Hub must keep measuring; the next violation photo fetch reconnects automatically. Dashboard's `cam-status` should flip to offline and back.
- Watch hub serial for brownout resets — a reset means power rail problems ([HARDWARE.md §5.4](HARDWARE.md#54-power-design--four-independent-supplies)).
- With the UPS fitted, add a 4 h battery-only run per hub + CAM rail (bench test B13, [HARDWARE.md §5.5](HARDWARE.md#55-battery-backup-ups-option--one-18650-per-supply)) — one full outage per device before acceptance.

## 5. Usability (SSU panel)

Per the methodology, SSU personnel are test users:

1. Recruit 3–5 SSU staff (the actual dashboard users).
2. Task list: *"Open the dashboard. Check the live feed is working. Find today's violations. View the photo of the fastest one. Filter to confirmed-only. Mark it reviewed."*
3. Time each user; note where they hesitate or ask for help.
4. One-page feedback form: ease-of-use 1–5, confidence in data 1–5.
5. Pass: all users complete tasks unaided in < 3 min; mean ease ≥ 4/5.

## 6. Evaluation Scoring Sheet (ISO/IEC 25010 mapping)

Score each 1–5 across the test battery; these feed the capstone results chapter:

| Criterion (paper) | ISO/IEC 25010 characteristic | Evidence source | Score (1–5) |
|---|---|---|---|
| Accuracy | Functional suitability | §2 calibration error | |
| Response Time | Performance efficiency | §3 timing logs | |
| Reliability | Reliability | §4 soak results | |
| Usability | Usability | §5 SSU panel | |
| Data Accessibility | Maintainability/Portability | Dashboard retrieval live + history query | |

ISO/IEC 30141 (IoT architecture) checklist — yes/no per item:

- [ ] Devices interact through defined interfaces (hub↔CAM HTTP, hub↔API JSON contract)
- [ ] Data flow: device → network → cloud → dashboard, all observable
- [ ] Scalable to N poles (schema accepts multiple `device_id`s; each pole = 1 hub + 1 CAM)
- [ ] Failure isolation: CAM down ≠ hub down ≠ dashboard down; microSD backup covers photo gaps

## 7. Test Log Templates

### Calibration log

```
Date: ____  Mount angle: ____°  Firmware: ____  Reference: ____
Run | Method (ref speed)        | Displayed peak kph | Ref kph | Error %
 1  | car @ GPS 15 km/h         |                    |         |
 2  | car @ GPS 15 km/h         |                    |         |
...
Mean |σ| error: ____ %   Detection rate: ____/____ passes   Confirmed rate: ____/____
```

### Soak log

```
Start: ____  End: ____ (48 h)
Reboots (hub/CAM): ____/____   Missed events: ____/____   WiFi drops: ____
Longest outage: ____ min   SD photos present: Y/N   CAM power-cycle recovery: Y/N
```

### UPS runtime log (B13 — one per device)

```
Device/Pole: ____   Rail (hub / CAM / TX#1 / TX#2): ____   Date: ____
Start: ____   End: ____ (4 h)
Cell voltage start: ____ V   At hour 4: ____ V   Rail at hour 4: ____ V
Events logged during outage: ____   Transfer clean (B12): Y/N   Full recharge overnight: Y/N
```

### Incident log (used for the paper's data)

| Time | Speed (kph) | Doppler Hz | Confirmed | Plate OCR | OCR conf. | Reviewed by |
|---|---|---|---|---|---|---|
| | | | | | | |

## 8. Common Failures → Causes

| Observation | Likely cause | Fix |
|---|---|---|
| Serial shows Hz but speed ~½ expected | Radar variant IF scaling differs | Re-verify §3; recalibrate `HZ_PER_KPH`, document |
| Constant −5–10% on everything | Cosine error from mount angle | Measure angle; set `COSINE_ANGLE_DEG` |
| Phantom events with no vehicle | Branches/banners in beam cone; `MIN_SPEED_KPH` too low | Clear the beam corridor; raise the noise floor |
| `confirmed` never true | Beam #1 mis-aimed / DO divider missing / `BEAM_BREAKS_LOW` polarity wrong | Re-align far post; check §5.2 level; flip the polarity constant |
| CAM never prints `BEAM2 SNAP` | Beam #2 mis-aimed / its far-post supply dead / `CAM_BEAM_BREAKS_LOW` polarity wrong | Re-align TX #2; check supply #2; flip the CAM polarity constant |
| Photos serve but show the wrong car (stale plate frame) | `BEAM2_FRESH_MS` too long for the traffic pattern | Lower it (e.g. 5 s); B11 validates the stale-cache fallback |
| Hub can't fetch photo | CAM IP changed (DHCP) | Set DHCP reservation; update `CAM_IP` |
| Photos dark/blurry at night | OV5640 gain maxed, plate unreadable | Add lane lighting (Optimize phase); OCR retries nightly |
| OCR < 50% accuracy | Photo angle/distance wrong for plate size | Camera closer to plate height; capture at trigger zone |
| Dashboard misses records | Upload timeout on big photos | Lower CAM `frame_size` to VGA, or serve on campus LAN |
| CAM stream freezes | CAM heap fragmentation after days | CAM reboots nightly (add `ESP.restart()` at 02:00 in CAM sketch) |
| `SNAPSHOT: failed` at beam-break | CAM rebooting / wrong `CAM_IP` | close-time fallback retries once; verify CAM IP + `cam-status` |
| Rail sags the instant mains is pulled | MT3608 output set below rail voltage · SS34 reversed · cell uncharged | Re-set MT3608 to 5.0 V no-load; check SS34 band faces the rail; charge the cell fully before install |
| Battery bank drains in days with mains present | SS34 missing/backwards — battery branch backfeeds through the charger | Fit/verify SS34 on the **mains branch only**; confirm no voltage at TP4056 OUT with mains on |
| Hub speed readings go erratic during outages | Rail cap too small for the transfer instant | Keep the 470–1000 µF rail cap; re-run B12 |

Next: install on site → [DEPLOYMENT.md](DEPLOYMENT.md)

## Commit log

2026-09-06 SafeWay: initial commit — BOM (verified Lazada PH listings) + capstone paper
    - docs/BOM.md: 13-component bill of materials, all listings live-verified
    on Lazada PH (Sep 6 2026) with ratings, sold counts, seller info
    - references/safeway.pdf: capstone paper (44pp)
2026-09-06 Add README + full build guide series (docs/)
    - README.md: standard structure — about, how it works, features,
    hardware table, architecture diagram, repo structure, staged build
    guide index, evaluation criteria, team, docs index
    - docs/HARDWARE.md: wiring tables, pin map (SD 1-bit mode frees
    GPIO 12/13 for gates), power design, enclosure assembly, alignment
    - docs/FIRMWARE.md: full annotated ESP32-CAM sketch (interrupt
    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
2026-09-07 Rebuild guides for two-board architecture: ESP32 38-pin hub (CDM324 Doppler + HC-SR04 + buzzer) + ESP32-CAM-MB (camera only)
    - BOM: swap S3-CAM for CAM+MB bundle (₱498) + DIYUSER 38-pin (₱196) + HC-SR04 back in (₱45, per paper Table 4 item 4); new total ₱1,642
    - HARDWARE: hub pin map (radar GPIO34 input-only, HC-SR04 26/25, buzzer 27), CAM board camera-only, dual 5V adapters, radar-through-ABS enclosure, radar aiming + cosine error table
    - FIRMWARE: two sketches — safeway-cam (/capture + /stream MJPEG + SD backup) and safeway-hub (Doppler pulse counting 44.7 Hz/kph, peak-hold, HC-SR04 confirm, buzzer, photo fetch, upload)
    - BACKEND: schema doppler_hz + confirmed (drops gate_m/dt_ms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
2026-09-07 HARDWARE: add boot/WiFi pin-conflict audit table (GPIO 25/26/27 ADC2 note, GPIO 34 no-pullup caveat)
2026-09-07 Replace HC-SR04 ultrasonic with KY-008 laser break-beam presence confirm
    - BOM: drop HC-SR04; add KY-008 TX + photoresistor receiver pair, 22AWG
    2-core cable for the far-post run, far-post mounting; total 1,642 -> 1,901
    - HARDWARE: hub pin map (beam RX DO -> GPIO 25, GPIO 26 freed), wiring table,
    enclosure receiver window, far-post aiming, power note, checklist
    - FIRMWARE: hub sketch reworked — beam ISR (CHANGE) + 50ms debounce +
    BEAM_BREAKS_LOW polarity constant replaces HC-SR04 TRIG/ECHO polling;
    boot-time beam state report; tuning table updated
    - BACKEND/DEPLOYMENT/TESTING: confirmed flag semantics, dashboards,
    checklists, maintenance and fault tables updated to beam language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
2026-09-07 Add STACK.md — full technology stack reference
    Firmware (Arduino IDE 2.x + ESP32 core, both board targets), backend
    (FastAPI/uvicorn/SQLite/OpenALPR/pytesseract+OpenCV), frontend
    (Tailwind CDN + vanilla JS + MJPEG), hardware summary, and the
    rationale behind each POC-friendly choice.
2026-09-07 Add BLOCK-DIAGRAM.md, FLOWCHART.md, SYSTEM-ARCHITECTURE.md
    - Block diagram: hardware blocks, signal chains, power distribution,
    numbered data flows (photo fetch, incident POST, direct MJPEG)
    - Flowchart: 300ms hub event pipeline, beam ISR debounce, scenario
    truth table (radar x beam), server OCR pipeline, dashboard flow
    - System architecture: 5-layer view, component responsibilities,
    interface contract table (I1-I8), network topology, failure modes,
    POC-to-scale deployment path
2026-09-07 Convert block diagram, flowchart, and system architecture to Mermaid
    All diagrams now render natively on GitHub:
    - BLOCK-DIAGRAM: system blocks w/ subgraphs (far post, pole, server,
    SSU browser), numbered data flows, power distribution
    - FLOWCHART: hub event pipeline, CAM sketch loop, server OCR
    pipeline, dashboard session
    - SYSTEM-ARCHITECTURE: layered view, network topology, deployment
    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
2026-09-08 Convert README system architecture to Mermaid; fix STACK.md doc links
    - README front-page diagram now Mermaid (renders on GitHub), with
    links to the three detailed diagram docs
    - STACK.md relative links fixed (docs/ -> same-dir BOM/HARDWARE)
    - All 10 mermaid blocks parser-validated; full-repo link check clean
2026-09-09 Fix build-blockers and doc drift from full audit
    Firmware (FIRMWARE.md):
    - camera_config_t: pin_ssc_siod/sioc never existed -> pin_sccb_sda/scl
    (verified against espressif/esp32-camera driver header)
    - CAM server: replace blocking infinite MJPEG stream loop with
    per-request JPEG (/stream now serves one frame, no SD write) --
    single-client server could never answer /capture while SSU watched
    the live feed, so violations during live view uploaded photoless
    - fb_count 2 + fb_location PSRAM: keep WiFi heap free; VGA note for
    no-PSRAM clone boards
    - Hub: merge fetchPhotoB64+uploadIncident -> base64 chunks stream into
    one pre-reserved POST body (kills the second 50-90KB heap copy /
    S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
2026-09-09 Swap camera board: ESP32-CAM-MB -> ESP32-S3 WROOM N16R8 CAM + OV5640
    - BOM: item 2 = ESP32-S3 N16R8 + OV5640 board (P613, Lazada
    pdp-i5315228212, '+ domestic ov5640' variant); grand total ~P2,016
    - Compatibility validated: espressif esp32-camera supports ESP32-S3 +
    OV5640 (2592x1944); board's 24-pin DVP header lists OV5640
    - FIRMWARE: safeway-cam pin map replaced with verified DevKit N16R8
    CAM map (OCR of pinout card, cross-checked vs xiaozhi-esp32
    bread-compact-wifi-s3cam config, 14/14 match); SD_MMC.setPins
    39/38/40; flashing section: ESP32S3 Dev Module, 16MB, OPI PSRAM,
    CH343P driver; PWDN/RESET not wired
    - HARDWARE: section 2.2 rewritten (board facts, 3.3V-only GPIO
    warning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
2026-09-11 Snapshot photo at beam-break: capture plate at the pole, buffer base64, POST on lane clear
    - Hub now fetches CAM /capture the instant the beam breaks (vehicle at
    the pole, plate in frame) instead of at event close
    - Photo buffered in persistent photoB64 String (keeps heap capacity
    across events - no fragmentation); fallback close-time snapshot if
    beam never broke
    - POST happens once the lane clears; body pre-reserved, timeouts set
    (4 s fetch / 8 s POST)
    - Docs synced: README, BLOCK-DIAGRAM, FLOWCHART, HARDWARE, STACK,
    SYSTEM-ARCHITECTURE, TESTING
2026-09-11 Add Cirkit Designer wiring diagram; reference it across docs
    - New wiring/circuit_image.png (3000x2056 export, editable at
    app.cirkitdesigner.com/project/192cfce5)
    - README: hardware section pointer, doc index row, repo tree entry
    - HARDWARE: diagram embedded above the §5 wiring tables (tables stay
    the authoritative pin-by-pin reference)
    - BOM, BLOCK-DIAGRAM, FIRMWARE, STACK, TESTING: cross-references
2026-09-11 Split power: 4 supplies, dual far-post beams, CAM self-trigger
    - HARDWARE: 2nd KY-008 pair (RX#2 on CAM GPIO 21), power design
    rewritten around four independent supplies (no shared rails, no
    cable crosses the road), spares + enclosure glands updated
    - BOM: 2x KY-008 TX + 2 compact far-post supplies; 22AWG road run
    dropped; totals recomputed (recommended build now P2,328)
    - FIRMWARE: CAM beam#2 ISR self-triggers snapshot + latest-photo
    cache on /capture; hub fetches cached frame
    - BLOCK-DIAGRAM / SYSTEM-ARCHITECTURE / FLOWCHART / STACK: second
    beam, 4-supply power diagram, failure modes, interfaces
    - TESTING / DEPLOYMENT: beam#2 bench tests, far-post power survey
    + teardown update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
2026-09-14 Updated 3d models and other files
    [SafeWay.f3z]
2026-09-16 Add LM358 radar chain as-built, 18650 UPS backup (16 cells, 4h), updated tests and maintenance
    🤖 Generated with Codebuff
2026-09-16 Sync block diagram: LM358 in signal chain, 18650 UPS on all four supplies
    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
